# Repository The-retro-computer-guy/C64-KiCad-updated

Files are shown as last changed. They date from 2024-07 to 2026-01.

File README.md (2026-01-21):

# The C64 250407 replica

A replica of the Commodore 64 Ver.250407  Rev.B motherboard, and matching schematics.

The replica project was started by Michael K. (Der Alte Bastler) in 2019 to learn SprintLayout, and the process of reverse engineering printed circuit boards. I finished the layout in SprintLayout, and imported it to KiCad. The KU motherboard schematics are nowhere to be found on the internet. Therefore I used the 250407 Reb.B schematics as reference and then modified them to match the KU motherboard layout.

The board has been prototyped and tested by Langwell Cowan and I.

We are not the first to reverse engineer this board; but we are the first to share the design files online.

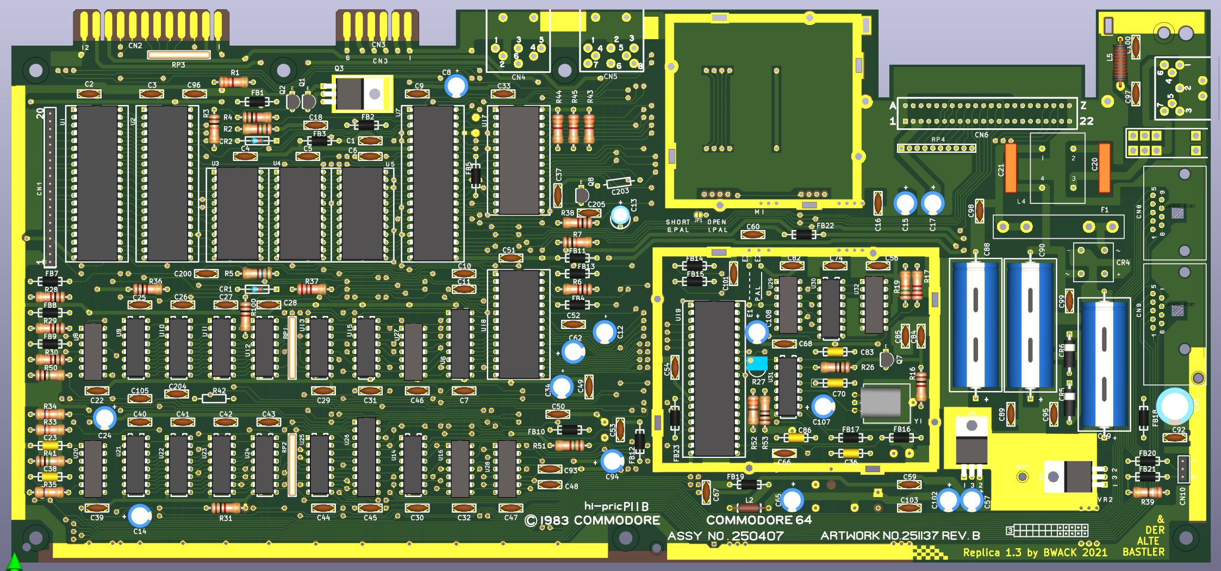
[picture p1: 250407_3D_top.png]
screenshot top

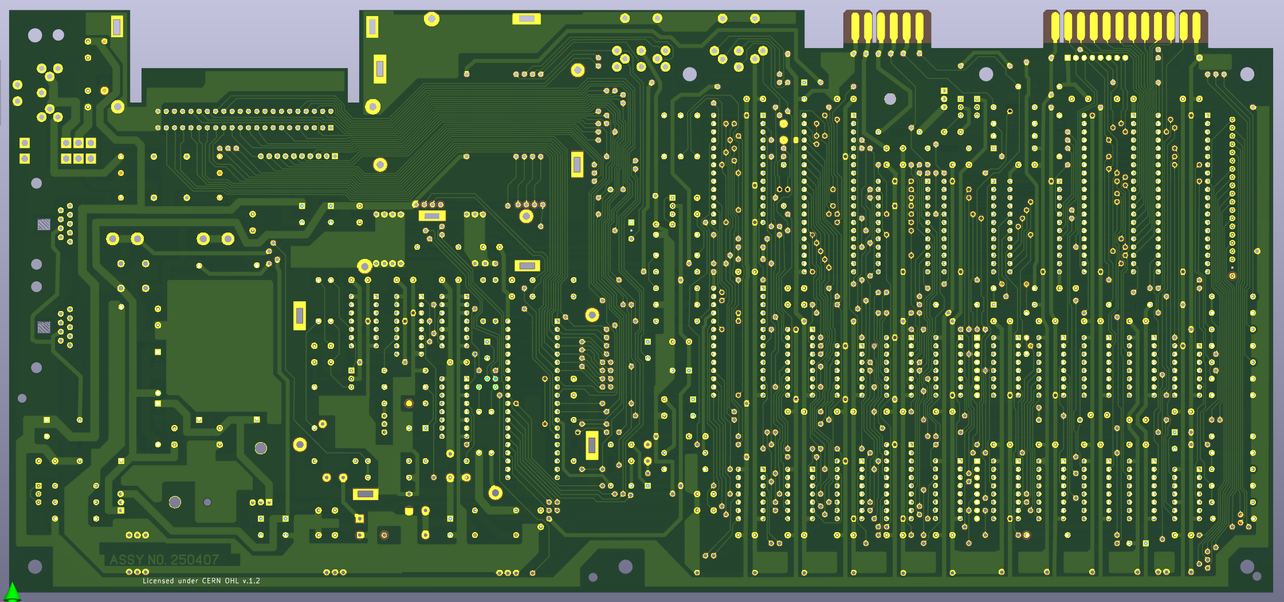
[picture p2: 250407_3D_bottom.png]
screenshot bottom


# BOM

Please see the [BOM file](250407_bom.csv).

Note that some values were left blank because they depend on the clock circuit (PAL/NTSC), and PLA model. They never made it into the schematics. You can find them in a table to the right of the schematics for 250407.
http://www.zimmers.net/anonftp/pub/cbm/schematics/computers/c64/index.html

# Interactive-BOM

[The interactive bom html page](https://htmlpreview.github.io/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) is a useful tool for assembling the board and finding signal traces via a web browser. To order parts, Use the BOM document listed above. (Mouser and Digikey compatable)



# Schematics

Download the PDF file [250407_.pdf](250407_.pdf) for high quality schematics.
Checkout [this tweet](https://twitter.com/paulrickards/status/1371988589974847492) by Paul Rickards where he plots the KU motherboard schematics KU-14194HB :-)

# Change log
- 2025-06-09: PCB and Schematics V1.3: PAL-NTSC jumpers fox. Thank you, Fred Sauer!
Note: V1.3 was opened and saved in KiCAD 9.0.1. I've verified the new gerbers. Things to beware of I you want to modify the design: 1. If you try to load changes from schematic into the PCBNew, KiCAD will require you to annotate the schematics, which in turn will replace all the resistor array sub parts. Example R1A will become R1A1, which will turn into new parts in PCBNew. Therefore I have not done that in this update. I have only changed the silkscreen, and I have only edited the schematics. 2. KiCAD will ask you to refill the zone fills. I have not done that because it also warns you about some change in fill-constrains. I don't remember exactly what, but I did not refill the fill zones when going to V1.3.
- 2022-08-18: Schematics V1.2: symbol and ERC fixes (Pull request from Gabriele Gorla/GGLABS)
- 2020-06-19: PCB and schematics V1.1: First release
- 2020-04-22: PCB and schematics V1.0: Prototype

# YouTube

Part 1-4:

IMAGE ALT TEXT HERE (https://www.youtube.com/watch?v=ox3BLlNSVFU)
IMAGE ALT TEXT HERE (https://www.youtube.com/watch?v=tBIvXRH-Mj0)
IMAGE ALT TEXT HERE (https://www.youtube.com/watch?v=Mg0gVhXbaxc)
IMAGE ALT TEXT HERE (https://www.youtube.com/watch?v=UPUVA1PZOOk)

# License and Disclaimer

Copyright Bwack 2025

This documentation describes Open Hardware and is licensed under the CERN OHL v. 1.2.

You may redistribute and modify this documentation under the terms of theCERN OHL v.1.2. (http://ohwr.org/cernohl). This documentation is distributed WITHOUT ANY EXPRESS OR IMPLIED WARRANTY, INCLUDING OF MERCHANTABILITY, SATISFACTORY QUALITY AND FITNESS FOR APARTICULAR PURPOSE. Please see the CERN OHL v.1.2 for applicable conditions.

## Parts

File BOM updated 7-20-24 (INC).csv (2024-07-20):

54 | 0.1 | Cap MLCC 0.1uF 50V X7R P5.08mm Radial | 80-C322C104K5R5TA | Order Quantity | Manufacturer Name | Datasheet URL | Quoted Part Number | Order Price | Min\Mult Order Qty
15 | 10uF | Cap Alu 10uF 25V 5x5mm P2.5mm Radial | 667-ECE-A1EKS100I | 15 | Panasonic | https://www.mouser.com/datasheet/2/315/ABA0000C1059-947582.pdf | 667-ECE-A1EKS100I | $0.12 | 1\1
2 | 470pF | Cap MLCC 470pF X7R Axial | 594-A471K15X7RF5UAA | 2 | Vishay | https://www.vishay.com/doc?45164 | 594-A471K15X7RF5UAA | $0.26 | 1\1
1 | 2200uF | Cap Elyt 2200uF 16V 15x30mm Axial | 594-2222-021-16222 | 1 | Vishay | https://www.vishay.com/doc?28264 | 594-2222-021-16222 | $4.66 | 1\1
2 | 0.22 | Cap Polyester Film 0.22uF 63VAC P10mm | 594-2222-368-25224 | 2 | Vishay | https://www.vishay.com/doc?28171 | 594-2222-368-25224 | $0.65 | 1\1
1 | 360pF | Cap MLCC 350pF 50V C0G Axial | 594-A331J15C0GF5TAA | 1 | Vishay | https://www.vishay.com/doc?45164 | 594-A331J15C0GF5TAA | $0.31 | 1\1
1 | 20pF | Cap MLCC 20pF C0G Axial | 581-SA102A200JAR | 1 | KYOCERA AVX | https://www.mouser.com/datasheet/2/40/SASprinGuard-1158830.pdf | 581-SA102A200JAR | $0.47 | 1\1
1 | 51pF | Cap MLCC 51pF (47pF OK) X7R Axial | 581-SA102A470JAR | 1 | KYOCERA AVX | https://www.mouser.com/datasheet/2/40/SASprinGuard-1158830.pdf | 581-SA102A470JAR | $0.37 | 1\1
2 | 1800pF | Cap MLCC 1800pF X7R Axial | 581-SA101C182KAR | 2 | KYOCERA AVX | https://www.mouser.com/datasheet/2/40/SASprinGuard-1158830.pdf | 581-SA101C182KAR | $0.43 | 1\1
1 | 15pF 5% | Cap MLCC 15pF 50V 5% C0G Axial/Radial Leaded | 594-A150J15C0GH5TAA | 1 | Vishay | https://www.vishay.com/doc?45164 | 594-A150J15C0GH5TAA | $0.31 | 1\1
1 | 0.47 | Cap MLCC 0.47uF +80/-20% X7R P5.08mm Radial | 80-C330C474K5R | 1 | KEMET | https://www.mouser.com/datasheet/2/447/KEM_C1050_GOLDMAX_X7R-3316381.pdf | 80-C330C474K5R | $0.43 | 1\1
2 | 82pF | Cap MLCC 82pF 100V C0G Axial / Radial Disc | 80-C410C820J1G | 2 | KEMET | https://www.mouser.com/datasheet/2/447/KEM_C1040_AXIMAX_C0G-3316406.pdf | 80-C410C820J1G | $0.31 | 1\1
1 | 1000uF | Cap Elyt 1000uF 16V 20% 10x30mm Axial | 594-2222-021-15102 | 1 | Vishay | https://www.vishay.com/doc?28264 | 594-2222-021-15102 | $3.71 | 1\1
1 | 470uF | Cap Elyt 470uF 50V 20% 13x26mm Axial | 598-477TTA050M | 1 | Cornell Dubilier | https://www.cde.com/resources/catalogs/TTA.pdf | 598-477TTA050M | $2.25 | 1\1
1 | 100uF | Cap Elyt 100uF 16V 20% 6.3x11mm Radial | REA101M1CBK-0611P | 1 | Lelon | https://www.mouser.com/datasheet/2/231/lelon_REA[1]-1174811.pdf | 140-REA101M1CBK0611P |  | 1\1
2 | 0.22 | Cap MLCC 0.22uF 50V X7R P5.08mm Radial | 80-C330C224K1R | 2 | KEMET | https://www.mouser.com/datasheet/2/447/KEM_C1050_GOLDMAX_X7R-3316381.pdf | 80-C330C224K1R | $0.38 | 1\1
1 | KEYBOARD_20PIN_MALE | Pin Header 20 POS P2.54mm male vertical | 538-22-28-4204 | 1 | Molex | https://www.molex.com/en-us/products/part-detail/22284204?display=pdf | 538-22-28-4204 | $1.67 | 1\1
1 | LED_CONNECTOR | Pin Header 3 POS P2.54mm male vertical | 538-22-28-4033 | 1 | Molex | https://www.molex.com/en-us/products/part-detail/22284033?display=pdf | 538-22-28-4033 | $0.28 | 1\1
2 | CONTROL_PORT | Standard Connector DSUB E09P RA590 | 571-5747467-1 | 2 | TE Connectivity | https://www.mouser.com/datasheet/2/418/9/ENG_CS_82068_AMPLIMITE_Right_Angle_Posted_Conn_041-3352032.pdf | 571-5747467-1 | $7.10 | 1\1
1 | IN4371 | Zener Diode 2.7V 500mW DO-35-2 | 78-TZX2V7A | 1 | Vishay | https://www.vishay.com/doc?95449 | 78-TZX2V7A | $0.23 | 1\1
1 | IN755 | Zener Diode 7.5V 500mW DO-35-2 | 78-TZX7V5C | 1 | Vishay | https://www.vishay.com/doc?95449 | 78-TZX7V5C | $0.23 | 1\1
1 | BRIDGE_RECTIFIER | Bridge Rectifier 2A 600V Vf=1.05V | 627-S2VB60-5000 | 1 | Shindengen | https://www.mouser.com/datasheet/2/366/J534S2VB-1203088.pdf | 627-S2VB60-5000 | $2.49 | 1\1
2 | 1N4001 | Rectifier 1A Vr=50V | 625-1N4001-E3/54 | 2 | Vishay | https://www.vishay.com/doc?88840 | 625-1N4001-E3/54 | $0.33 | 1\1
2 | 1A | Fuse Clips (buy two) | 504-BK/1A1907-03-R | 2 | Eaton | https://www.mouser.com/datasheet/2/87/eaton_1axxxx_pcb_fuse_clips_atc_atm_blade_data_she-1608562.pdf | 504-BK/1A1907-03-R | $0.70 | 1\1
9 | FERRITE_BEAD | Ferrite Bead D3.5 L4.45mm Axial | 623-2743001112LF | 9 | Fair-Rite | https://www.mouser.com/datasheet/2/150/2743001112-1512844.pdf | 623-2743001112LF | $0.14 | 1\1
13 | FERRITE_NARROW | Ferrite Bead D3.5 L4.45mm Axial | 623-2743001112LF | 13 | Fair-Rite | https://www.mouser.com/datasheet/2/150/2743001112-1512844.pdf | 623-2743001112LF | $0.076 | 1\1
1 | 2.2uH | Inductor 2.2uH 5% Radial | 652-78F2R2J-RC | 1 | Bourns | https://www.mouser.com/datasheet/2/54/78f_series-777133.pdf | 652-78F2R2J-RC | $0.31 | 1\1
1 | CHOKE | Common Mode Choke 250V 3.8mH 2.1A 150mOhms | 80-SSR10V-21038 | 1 | KEMET | https://www.mouser.com/datasheet/2/447/KEM_LF0042_SSR10V_H-3316793.pdf | 80-SSR10V-21038 | $1.92 | 1\1
1 | 1.2uH | Inductor 1.5uH 10% Radial | 542-5800-4R7-RC | 1 | Bourns | https://www.mouser.com/datasheet/2/54/5800_series-776803.pdf | 542-5800-4R7-RC | $1.46 | 1\1
4 | 2SC1815 | Bipolar Transistor TO-92 Vce=60V 400mA | 2SC1815 | 4 | Central Semiconductor | https://my.centralsemi.com/datasheets/2SC1815.PDF | 610-2SC1815-Y | $0.93 | 1\1
1 | TP29B/2SD880 | Bipolar Transistor TO-220 | 512-KSD880YTU | 1 | onsemi | https://www.mouser.com/datasheet/2/308/1/KSD880_D-2314642.pdf | 512-KSD880YTU | $0.77 | 1\1
4 | 3K3 | Resistor 3K3 0207 Axial | 594-MBB02070C3301FC1 | 4 | Vishay | https://www.vishay.com/doc?28919 | 594-MBB02070C3301FC1 | $0.63 | 1\1
2 | 2K7 | Resistor 2K7 0207 Axial | 594-MBB02070C2701FCT | 2 | Vishay | https://www.vishay.com/doc?28919 | 594-MBB02070C2701FCT | $0.36 | 1\1
1 | 15K | Resistor 15K 0207 Axial | 594-MBB02070C1502FC1 | 1 | Vishay | https://www.vishay.com/doc?28919 | 594-MBB02070C1502FC1 | $0.63 | 1\1
2 | 1.5K | Resistor 1K5 0207 Axial | 594-MBB02070C1501FCT | 2 | Vishay | https://www.vishay.com/doc?28919 | 594-MBB02070C1501FCT | $0.16 | 1\1
2 | 100 | Resistor 100 0207 Axial | 594-MBB02070C1000FCT | 2 | Vishay | https://www.vishay.com/doc?28919 | 594-MBB02070C1000FCT | $0.10 | 1\1
1 | 500 | Trimmer Resistor 500 Ohms Linear | 652-3306F-1-501 | 1 | Bourns | https://www.mouser.com/datasheet/2/54/3306-776934.pdf | 652-3306F-1-501 | $0.49 | 1\1
10 | 1K | Resistor 1K 0207 Axial | 594-MBB02070C1001FCT | 10 | Vishay | https://www.vishay.com/doc?28919 | 594-MBB02070C1001FCT | $0.095 | 1\1
2 | 10K | Resistor 10K 0207 Axial | 594-MBB02070C1002FCT | 2 | Vishay | https://www.vishay.com/doc?28919 | 594-MBB02070C1002FCT | $0.36 | 1\1
2 | 47K | Resistor 47K 0207 Axial | 594-MBB02070C4702FC1 | 2 | Vishay | https://www.vishay.com/doc?28919 | 594-MBB02070C4702FC1 | $0.50 | 1\1
1 | 470K | Resistor 470K 0207 Axial | 594-MBB02070C4703FCT | 1 | Vishay | https://www.vishay.com/doc?28919 | 594-MBB02070C4703FCT | $0.36 | 1\1
1 | 390 | Resistor 390 0207 Axial | 594-MBB02070C3900FCT | 1 | Vishay | https://www.vishay.com/doc?28919 | 594-MBB02070C3900FCT | $0.36 | 1\1
2 | 1M | Resistor 1M 0207 Axial | 594-MBB02070C1004FCT | 2 | Vishay | https://www.vishay.com/doc?28919 | 594-MBB02070C1004FCT | $0.16 | 1\1
1 | 560 | Resistor 560 0207 Axial | 594-MBB02070C5600FCT | 1 | Vishay | https://www.vishay.com/doc?28919 | 594-MBB02070C5600FCT | $0.36 | 1\1
1 | 330 | Resistor 330 0207 Axial | 594-MBB02070C3300FCT | 1 | Vishay | https://www.vishay.com/doc?28919 | 594-MBB02070C3300FCT | $0.16 | 1\1
2 | 33 | Resistor Network 33R Isolated 8 pin SIP | 652-4308R-2LF-33 | 2 | Bourns | https://www.mouser.com/datasheet/2/54/4300R-777281.pdf | 652-4308R-2LF-33 | $2.19 | 1\1
1 | R_ARRAY_7WAY_US | Resistor Network 3K3 Bussed 8 pin SIP | 774-77081332P | 1 | CTS | https://www.mouser.com/datasheet/2/96/770-786259.pdf | 774-77081332P | $3.49 | 1\1
1 | R_ARRAY_9WAY_US | Resistor Network 3K3 Bussed 10 pin SIP | 774-770101332P | 1 | CTS | https://www.mouser.com/datasheet/2/96/770-786259.pdf | 774-770101332P | $3.90 | 1\1
1 | 74LS258 | QUADRUPLE 2-LINE TO 1-LINE DATA SELECTORS/MULTIPLEXERS | 595-SN74LS258BN | 1 | Texas Instruments | https://www.ti.com/lit/gpn/sn74ls257b | 595-SN74LS258BN | $1.10 | 1\1
1 | 74LS139 | DUAL 2-LINE TO 4-LINE DECODERS/MULTIPLEXERS | 595-SN74LS139AN | 1 | Texas Instruments | https://www.ti.com/lit/gpn/sn54ls139a | 595-SN74LS139AN | $0.78 | 1\1
1 | 556 | DUAL PRECISION TIMERS | 595-NE556N | 1 | Texas Instruments | https://www.ti.com/lit/gpn/ne555 | 595-NE556N | $0.46 | 1\1
2 | 74LS257 | QUADRUPLE 2-LINE TO 1-LINE DATA SELECTORS/MULTIPLEXERS | 595-SN74LS257BN | 2 | Texas Instruments | https://www.ti.com/lit/gpn/sn74ls257b | 595-SN74LS257BN | $0.97 | 1\1
1 | 74LS373 | OCTAL D-TYPE TRANSPARENT LATCHES AND EDGE-TRIGGERED FLIP-FLOPS | 595-SN74LS373N | 1 | Texas Instruments | https://www.ti.com/lit/gpn/sn74ls373 | 595-SN74LS373N | $0.92 | 1\1
1 | 7408 | QUADRUPLE 2-INPUT POSITIVE-AND GATES | 595-SN74LS08N | 1 | Texas Instruments | https://www.ti.com/lit/gpn/sn74ls08 | 595-SN74LS08N | $0.81 | 1\1
2 | 4066 | CMOS Quad Bilateral Switch | 595-CD4066BE | 2 | Texas Instruments | https://www.ti.com/lit/gpn/cd4066b | 595-CD4066BE | $0.87 | 1\1
1 | 74LS74 | DUAL D-TYPE POSITIVE-EDGE-TRIGGERED FLIP-FLOPS WITH PRESET AND CLEAR | 595-SN74LS74AN | 1 | Texas Instruments | https://www.ti.com/lit/gpn/sn74ls74a | 595-SN74LS74AN | $0.57 | 1\1
1 | 74LS193 | SYNCHRONOUS 4-BIT UP/DOWN COUNTERS (DUAL CLOCK WITH CLEAR) | 595-SN74LS193N | 1 | Texas Instruments | https://www.ti.com/lit/gpn/sn74ls193 | 595-SN74LS193N | $1.25 | 1\1
1 | 74LS629N | VOLTAGE-CONTROLLED OSCILLATORS | 595-SN74LS629N | 1 | Texas Instruments | https://www.ti.com/lit/gpn/sn74ls629 | 595-SN74LS629N | $5.93 | 1\1
1 | 7406N | HEX INVERTER BUFFERS/DRIVERSWITH OPEN-COLLECTOR HIGH-VOLTAGE OUTPUTS | 595-SN7406N | 1 | Texas Instruments | https://www.ti.com/lit/gpn/sn7406 | 595-SN7406N | $0.95 | 1\1
1 | 7812 | Linear Voltage Regulators 12V 1A Positive | 863-MC7812CTG | 1 | onsemi | https://www.mouser.com/datasheet/2/308/1/MC7800_D-2315963.pdf | 863-MC7812CTG | $0.62 | 1\1
1 | 7805 | Linear Voltage Regulators 5V 1A Positive | 863-MC7805CTG | 1 | onsemi | https://www.mouser.com/datasheet/2/308/1/MC7800_D-2315963.pdf | 863-MC7805CTG | $0.62 | 1\1
1 | Crystal | Crystals HC49/U | 815-AB-17.734475-B4 | 1 | ABRACON | https://www.mouser.com/datasheet/2/3/ab-39594.pdf | 815-AB-17.734475-B4 | $0.75 | 1\1
4 |  | Socket PDIP 40P P2.54mm W15.24mm DUAL WIPE | 517-4840-6000-CP | 4 | 3M | https://www.mouser.com/datasheet/2/1/28ee42f6da6f8c4339adfd7d572e1cf1acfab337-2951721.pdf | 517-4840-6000-CP | $1.18 | 1\1
2 |  | Socket PDIP 28P P2.54mm W15.24mm DUAL WIPE | 517-4828-6000-CP | 2 | 3M | https://www.mouser.com/datasheet/2/1/28ee42f6da6f8c4339adfd7d572e1cf1acfab337-2951721.pdf | 517-4828-6000-CP | $1.07 | 1\1
3 |  | Socket PDIP 24P P2.54mm W15.24mm DUAL WIPE | 517-4824-6000-CP | 3 | 3M | https://www.mouser.com/datasheet/2/1/28ee42f6da6f8c4339adfd7d572e1cf1acfab337-2951721.pdf | 517-4824-6000-CP | $0.74 | 1\1
1 |  | Socket PDIP 20P P2.54mm W7.62mm DUAL WIPE | 517-4820-3000-CP | 1 | 3M | https://www.mouser.com/datasheet/2/1/28ee42f6da6f8c4339adfd7d572e1cf1acfab337-2951721.pdf | 517-4820-3000-CP | $0.80 | 1\1
1 |  | Socket PDIP 18P P2.54mm W7.62mm DUAL WIPE | 517-4818-3000-CP | 1 | 3M | https://www.mouser.com/datasheet/2/1/28ee42f6da6f8c4339adfd7d572e1cf1acfab337-2951721.pdf | 517-4818-3000-CP | $0.65 | 1\1
14 |  | Socket PDIP 16P P2.54mm W7.62mm DUAL WIPE | 517-4816-3000-CP | 14 | 3M | https://www.mouser.com/datasheet/2/1/28ee42f6da6f8c4339adfd7d572e1cf1acfab337-2951721.pdf | 517-4816-3000-CP | $0.383 | 1\1
7 |  | Socket PDIP 14P P2.54mm W7.62mm DUAL WIPE | 517-4814-3000-CP | 7 | 3M | https://www.mouser.com/datasheet/2/1/28ee42f6da6f8c4339adfd7d572e1cf1acfab337-2951721.pdf | 517-4814-3000-CP | $0.49 | 1\1

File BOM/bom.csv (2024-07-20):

Reference | Quantity | Value | Footprint | Mouser P/N | Reichelt P/N | Other
C96 C22 C47 C3 C2 C9 C105 C39 C46 C18 C1 C99 C98 C92 C95 C89 C59 C103 C68 C74 C67 C84 C56 C66 C82 C200 C44 C28 C43 C27 C42 C26 C41 C25 C40 C29 C4 C5 C6 C33 C31 C30 C7 C32 C45 C101 C60 C54 C53 C16 C49 C50 C52 C51 | 54 | .1 | Cap MLCC 0.1uF 50V X7R P5.08mm Radial | 80-C322C104K5R5TA or 581-SR215C104KART | X7R-5 100N
C8 C24 C57 C102 C65 C17 C94 C15 C13 C34 C62 C12 C14 C107 C108 | 15 | 10uF | Cap Alu 10uF 25V 5x5mm P2.5mm Radial | 667-ECE-A1EKS100I | M 10U 25
C11 C10 | 2 | 470pF | Cap MLCC 470pF X7R Axial | 594-A471K15X7RF5UAA | ?
C19 | 1 | 2200uF | Cap Elyt 2200uF 16V 15x30mm Axial | 594-2222-021-16222 or 594-2222-021-15222 or 598-228TTA016M | COS 105 2200/16
C203 | 1 | ? | KU-14194HB-RevB-KiCad:CAPACITOR_RADIAL_P13.97_L9.9_D3.6 | ~
C204 | 1 | ? | KU-14194HB-RevB-KiCad:CAP_P5.08mm | ~
C205 | 1 | 220pF | KU-14194HB-RevB-KiCad:CAP_P5.08mm | ~
C21 C20 | 2 | .22 | Cap Polyester Film 0.22uF 63VAC P10mm | 594-2222-368-25224 | MKS4-100 220N2
C23 | 1 | 360pF | Cap MLCC 350pF 50V C0G Axial | 594-A331J15C0GF5TAA | ?
C36 | 1 | 20pF | Cap MLCC 20pF C0G Axial | 581-SA102A200JAR | ?
C37 | 1 | 1000pF | KU-14194HB-RevB-KiCad:CAP_P5.08mm | ~
C38 | 1 | 51pF | Cap MLCC 51pF (47pF OK) X7R Axial | 581-SA102A470JAR | ?
C48 C93 | 2 | 1800pF | Cap MLCC 1800pF X7R Axial | 581-SA101C182KAR | ?
C70 | 1 | 15pF 5% | Cap MLCC 15pF 50V 5% C0G Axial/Radial Leaded | 594-A150J15C0GH5TAA | KERKO 15P
C85 | 1 | .47 | Cap MLCC 0.47uF +80/-20% X7R P5.08mm Radial | 80-C330C474K5R or 81-RCER71H474K1K1H3B | Z5U-5 470N
C86 C83 | 2 | 82pF | Cap MLCC 82pF 100V C0G Axial / Radial Disc | 80-C410C820J1G
C88 | 1 | 1000uF | Cap Elyt 1000uF 16V 20% 10x30mm Axial | 594-2222-021-15102 or 598-108TTA016M
C90 | 1 | 470uF | Cap Elyt 470uF 50V 20% 13x26mm Axial | 598-477TTA050M | COS 105 470/50
C91 | 1 | 100uF | Cap Elyt 100uF 16V 20% 6.3x11mm Radial | REA101M1CBK-0611P | FR-A 100U 16
C97 C100 | 2 | .22 | Cap MLCC 0.22uF 50V X7R P5.08mm Radial | 80-C330C224K1R | Z5U-5 220N
CN1 | 1 | KEYBOARD_20PIN_MALE | Pin Header 20 POS P2.54mm male vertical | 538-22-28-4204 | MPE 087-1-020
CN10 | 1 | LED_CONNECTOR | Pin Header 3 POS P2.54mm male vertical | 538-22-28-4033 | RND 205-00624
CN2 | 1 | USER_PORT_CON | KU-14194HB-RevB-KiCad:EDGE_CON_24P | -
CN3 | 1 | CASSETTE_PORT_CON | KU-14194HB-RevB-KiCad:EDGE_CON_12P_TAPE | -
CN4 | 1 | SERIAL_BUS_CON | KU-14194HB-RevB-KiCad:SERIAL_CON_DIN6
CN5 | 1 | AV_CONN | KU-14194HB-RevB-KiCad:AV_CON_DIN8 | -
CN6 | 1 | EXPANSION_PORT | Conn Edge Dual Female 44 POS P2.54mm |  | Digikey: H122591-ND
CN7 | 1 | POWER_CON | KU-14194HB-RevB-KiCad:POWER_CON_D7_250407
CN8 CN9 | 2 | CONTROL_PORT | Standard Connector DSUB E09P RA590 | 571-5747467-1
CR1 | 1 | IN4371 | Zener Diode 2.7V 500mW DO-35-2 | 78-TZX2V7A | ZF 2,7
CR100 CR102 CR101 CR103 | 4 | D_Small_ALT |  | ~
CR2 | 1 | IN755 | Zener Diode 7.5V 500mW DO-35-2 | 78-TZX7V5C | ZF 7,5
CR4 | 1 | BRIDGE_RECTIFIER | Bridge Rectifier 2A 600V Vf=1.05V | 627-S2VB60-5000 | KBPC604 DIO
CR5 CR6 | 2 | 1N4001 | Rectifier 1A Vr=50V | 625-1N4001-E3/54 or 625-1N4001-E3/53
E1 | 1 | JUMPER_WIRE | KU-14194HB-RevB-KiCad:JUMPER_WIRE | -
E2 | 1 | JUMPER_WIRE_DASHED | KU-14194HB-RevB-KiCad:JUMPER_WIRE | -
F1 | 2 | 1A | Fuse Clips (buy two) | 504-BK/1A1907-03-R
FB18 FB4 FB22 FB12 FB14 FB15 FB13 FB10 FB11 | 9 | FERRITE_BEAD | Ferrite Bead D3.5 L4.45mm Axial | 623-2743001112LF or 81-BL01RN1A2A2B | BEAD 8-21
FB7 FB9 FB8 FB5 FB2 FB1 FB3 FB20 FB21 FB17 FB16 FB19 FB23 | 13 | FERRITE_NARROW | Ferrite Bead D3.5 L4.45mm Axial | 623-2743001112LF or 81-BL01RN1A2A2B | BEAD 8-21
JP1 | 1 | Jumper_NC_Small | Jumper:SolderJumper-2_P1.3mm_Bridged_RoundedPad1.0x1.5mm | ~
L2 | 1 | 2.2uH | Inductor 2.2uH 5% Radial | 652-78F2R2J-RC | L-MICC 2,2µ
L4 | 1 | CHOKE | Common Mode Choke 250V 3.8mH 2.1A 150mOhms | 80-SSR10V-21038
L5 | 1 | 1.2uH | Inductor 1.5uH 10% Radial | 542-5800-4R7-RC | L-HBCC 1,5µ
M1 | 1 | MODULATOR_LONGBOARD | KU-14194HB-RevB-KiCad:MODULATOR_PORT_LONGBOARD | -
Q2 Q1 Q7 Q8 | 4 | 2SC1815 | Bipolar Transistor TO-92 Vce=60V 400mA | 2SC1815 | SC 1815
Q3 | 1 | TP29B/2SD880 | Bipolar Transistor TO-220 | 512-KSD880YTU | SD 880
R1 R43 R44 R45 | 4 | 3K3 | Resistor 3K3 0207 Axial | 594-MBB02070C3301FC1 | METALL 3,30K
R17 R37 | 2 | 2K7 | Resistor 2K7 0207 Axial | 594-MBB02070C2701FCT | METALL 2,70K
R19 | 1 | 15K | Resistor 15K 0207 Axial | 594-MBB02070C1502FC1 | METALL 15,0K
R2 R51 | 2 | 1.5K | Resistor 1K5 0207 Axial | 594-MBB02070C1501FCT | 1W 1,5K
R26 R53 | 2 | 100 | Resistor 100 0207 Axial | 594-MBB02070C1000FCT | METALL 100
R27 | 1 | 500 | Trimmer Resistor 500 Ohms Linear | 652-3306F-1-501 | BOU 3386P-1-501
R28 R30 R29 R36 R4 R16 R100 R31 R38 R6 | 10 | 1K | Resistor 1K 0207 Axial | 594-MBB02070C1001FCT | METALL 1,00K
R3 R7 | 2 | 10K | Resistor 10K 0207 Axial | 594-MBB02070C1002FCT | METALL 10,0K
R33 R34 | 2 | 47K | Resistor 47K 0207 Axial | 594-MBB02070C4702FC1 | METALL 47,0K
R35 | 1 | 470K | Resistor 470K 0207 Axial | 594-MBB02070C4703FCT | METALL 470K
R39 | 1 | 390 | Resistor 390 0207 Axial | 594-MBB02070C3900FCT | METALL 390
R41 R50 | 2 | 1M | Resistor 1M 0207 Axial | 594-MBB02070C1004FCT or 603-HHV-25JT-52-1M
R42 | 1 | ~ | KU-14194HB-RevB-KiCad:RESISTOR | - | -
R5 | 1 | 560 | Resistor 560 0207 Axial | 594-MBB02070C5600FCT | METALL 560
R52 | 1 | 330 | Resistor 330 0207 Axial | 594-MBB02070C3300FCT
RP1 RP2 | 2 | 33 | Resistor Network 33R Isolated 8 pin SIP | 652-4308R-2LF-33 or 268-33-RC
RP3 | 1 | R_ARRAY_7WAY_US | Resistor Network 3K3 Bussed 8 pin SIP | 774-77081332P
RP4 | 1 | R_ARRAY_9WAY_US | Resistor Network 3K3 Bussed 10 pin SIP | 774-770101332P
SW1 | 1 | POWER_SWITCH | KU-14194HB-RevB-KiCad:POWER_SWITCH
U1 | 1 | CIA_U1 | KU-14194HB-RevB-KiCad:DIP40 | -
U12 U24 U11 U23 U10 U22 U21 U9 | 8 | 4164-2 | KU-14194HB-RevB-KiCad:DIP16 | -
U14 | 1 | 74LS258 | QUADRUPLE 2-LINE TO 1-LINE DATA SELECTORS/MULTIPLEXERS | 595-SN74LS258BN
U15 | 1 | 74LS139 | DUAL 2-LINE TO 4-LINE DECODERS/MULTIPLEXERS | 595-SN74LS139AN
U17 | 1 | PLA_U17 | KU-14194HB-RevB-KiCad:DIP28 | -
U18 | 1 | 6581 | KU-14194HB-RevB-KiCad:DIP28 | -
U19 | 1 | VIC | KU-14194HB-RevB-KiCad:DIP40 | -
U2 | 1 | CIA_U2 | KU-14194HB-RevB-KiCad:DIP40 | -
U20 | 1 | 556 | DUAL PRECISION TIMERS | 595-NE556N
U25 U13 | 2 | 74LS257 | QUADRUPLE 2-LINE TO 1-LINE DATA SELECTORS/MULTIPLEXERS | 595-SN74LS257BN
U26 | 1 | 74LS373 | OCTAL D-TYPE TRANSPARENT LATCHES AND EDGE-TRIGGERED FLIP-FLOPS | 595-SN74LS373N
U27 | 1 | 7408 | QUADRUPLE 2-INPUT POSITIVE-AND GATES | 595-SN74LS08N
U28 U16 | 2 | 4066 | CMOS Quad Bilateral Switch | 595-CD4066BE
U29 | 1 | 74LS74 | DUAL D-TYPE POSITIVE-EDGE-TRIGGERED FLIP-FLOPS WITH PRESET AND CLEAR | 595-SN74LS74AN
U3 U4 | 2 | 2364A | KU-14194HB-RevB-KiCad:DIP24 BASIC AND KERNAL ROM | -
U30 | 1 | 74LS193 | SYNCHRONOUS 4-BIT UP/DOWN COUNTERS (DUAL CLOCK WITH CLEAR) | 595-SN74LS193N
U31 | 1 | 74LS629N | VOLTAGE-CONTROLLED OSCILLATORS | 595-SN74LS629N
U32 | 1 | MC4044 | KU-14194HB-RevB-KiCad:DIP14 | -
U5 | 1 | 2332A | KU-14194HB-RevB-KiCad:DIP24 CHAR ROM | -
U6 | 1 | 2114 | KU-14194HB-RevB-KiCad:DIP18 COLOR RAM | -
U7 | 1 | 6510_MPU | KU-14194HB-RevB-KiCad:DIP40 | -
U8 | 1 | 7406N | HEX INVERTER BUFFERS/DRIVERSWITH OPEN-COLLECTOR HIGH-VOLTAGE OUTPUTS | 595-SN7406N
VR1 | 1 | 7812 | Linear Voltage Regulators 12V 1A Positive | 863-MC7812CTG
VR2 | 1 | 7805 | Linear Voltage Regulators 5V 1A Positive | 863-MC7805CTG
Y1 | 1 | Crystal | Crystals HC49/U | 815-AB-17.734475-B4
Other:
 | Quantity |  | Description | mouser
 | 4 |  | Socket PDIP 40P P2.54mm W15.24mm DUAL WIPE | 517-4840-6000-CP
 | 2 |  | Socket PDIP 28P P2.54mm W15.24mm DUAL WIPE | 517-4828-6000-CP
 | 3 |  | Socket PDIP 24P P2.54mm W15.24mm DUAL WIPE | 517-4824-6000-CP
 | 1 |  | Socket PDIP 20P P2.54mm W7.62mm DUAL WIPE | 517-4820-3000-CP
 | 1 |  | Socket PDIP 18P P2.54mm W7.62mm DUAL WIPE | 517-4818-3000-CP
 | 14 |  | Socket PDIP 16P P2.54mm W7.62mm DUAL WIPE | 517-4816-3000-CP
 | 7 |  | Socket PDIP 14P P2.54mm W7.62mm DUAL WIPE | 517-4814-3000-CP

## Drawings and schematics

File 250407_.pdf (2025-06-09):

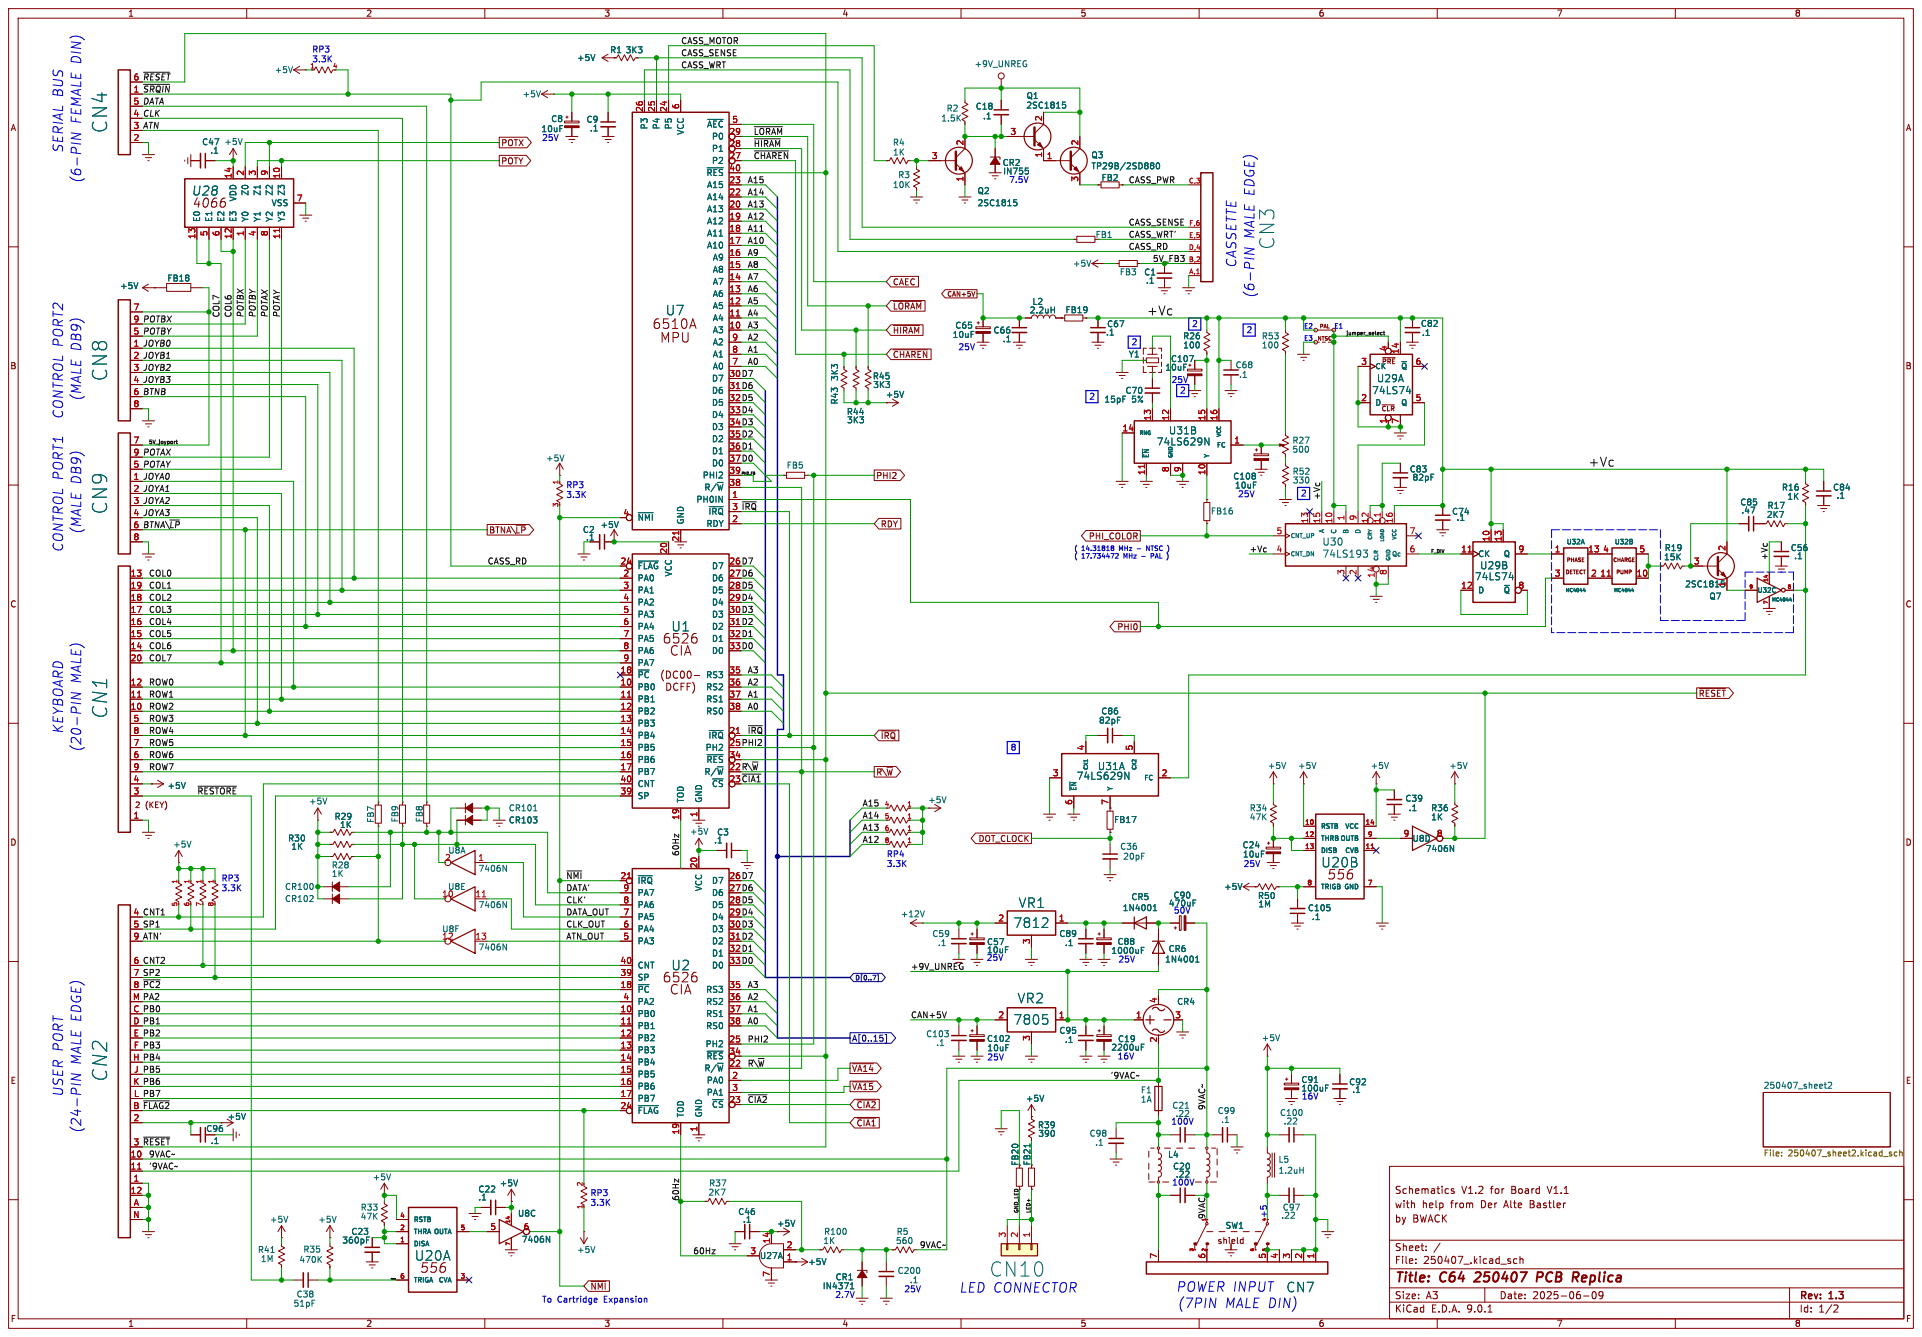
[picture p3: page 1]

6 GND 21 ~{AEC}5 P0 29 P1 28 P2 27 ~{RES}40 A15 23 A14 22 A13 20 A12 19 A11 18 A10 17 A9 16 A8 15 A7 14 A6 13 A5 12 A4 11 A3 10 A2 9 A1 8 A0 7 D7 30 D6 31 D5 32 D4 33 D3 34 D2 35 D1 36 D0 37 PHI2 39 R/~{W}38 PH0IN 1 ~{IRQ}3 RDY 2 U7

6 GND 21 ~{AEC}5 P0 29 P1 28 P2 27 ~{RES}40 A15 23 A14 22 A13 20 A12 19 A11 18 A10 17 A9 16 A8 15 A7 14 A6 13 A5 12 A4 11 A3 10 A2 9 A1 8 A0 7 D7 30 D6 31 D5 32 D4 33 D3 34 D2 35 D1 36 D0 37 PHI2 39 R/~{W}38 PH0IN 1 ~{IRQ}3 RDY 2 U1

9 2 CRY 12 CLR 14 LOAD 11 GND 8 VCC 16

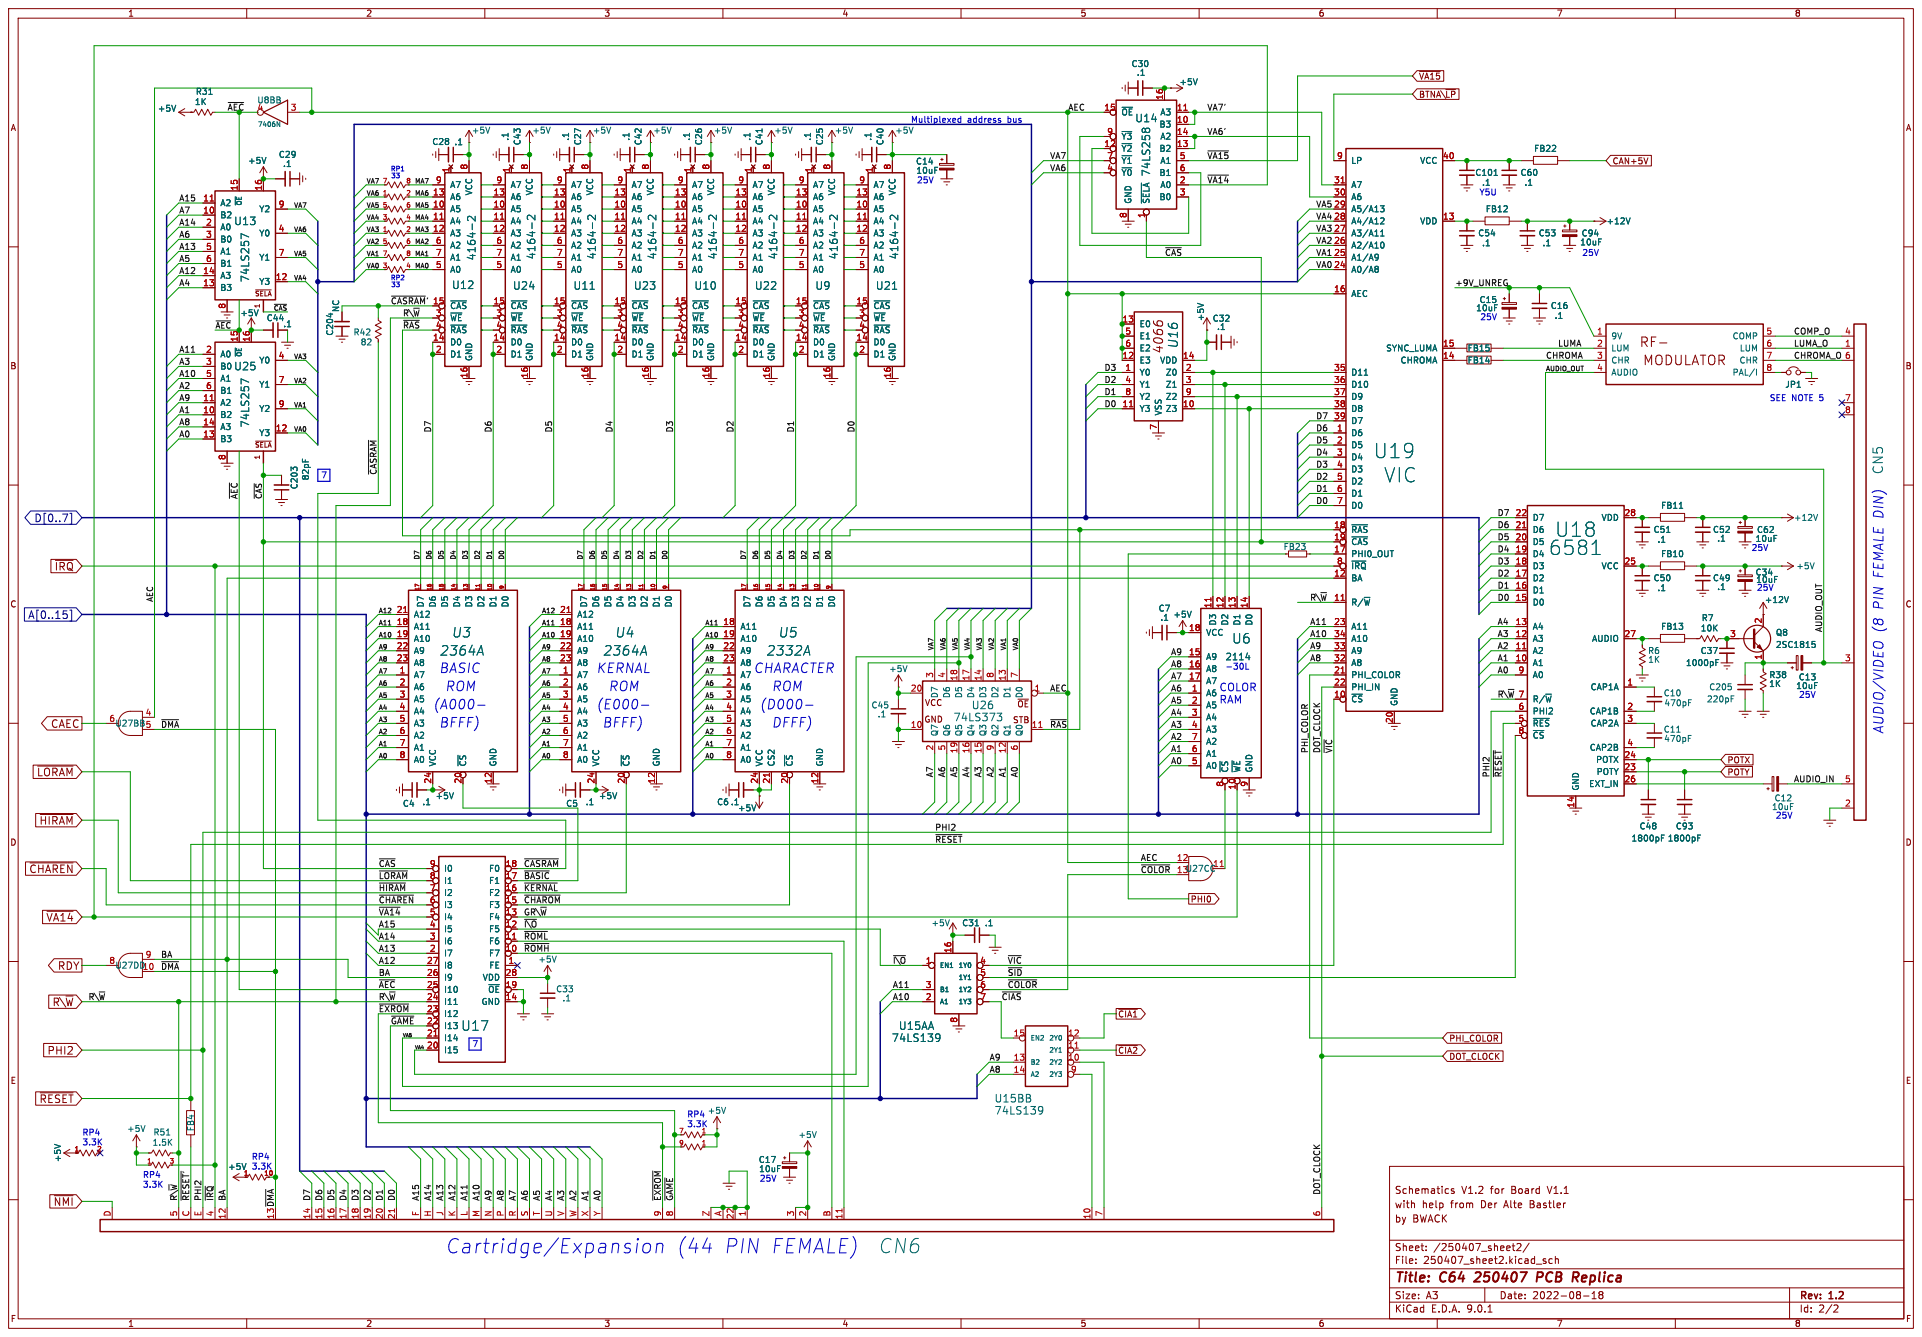
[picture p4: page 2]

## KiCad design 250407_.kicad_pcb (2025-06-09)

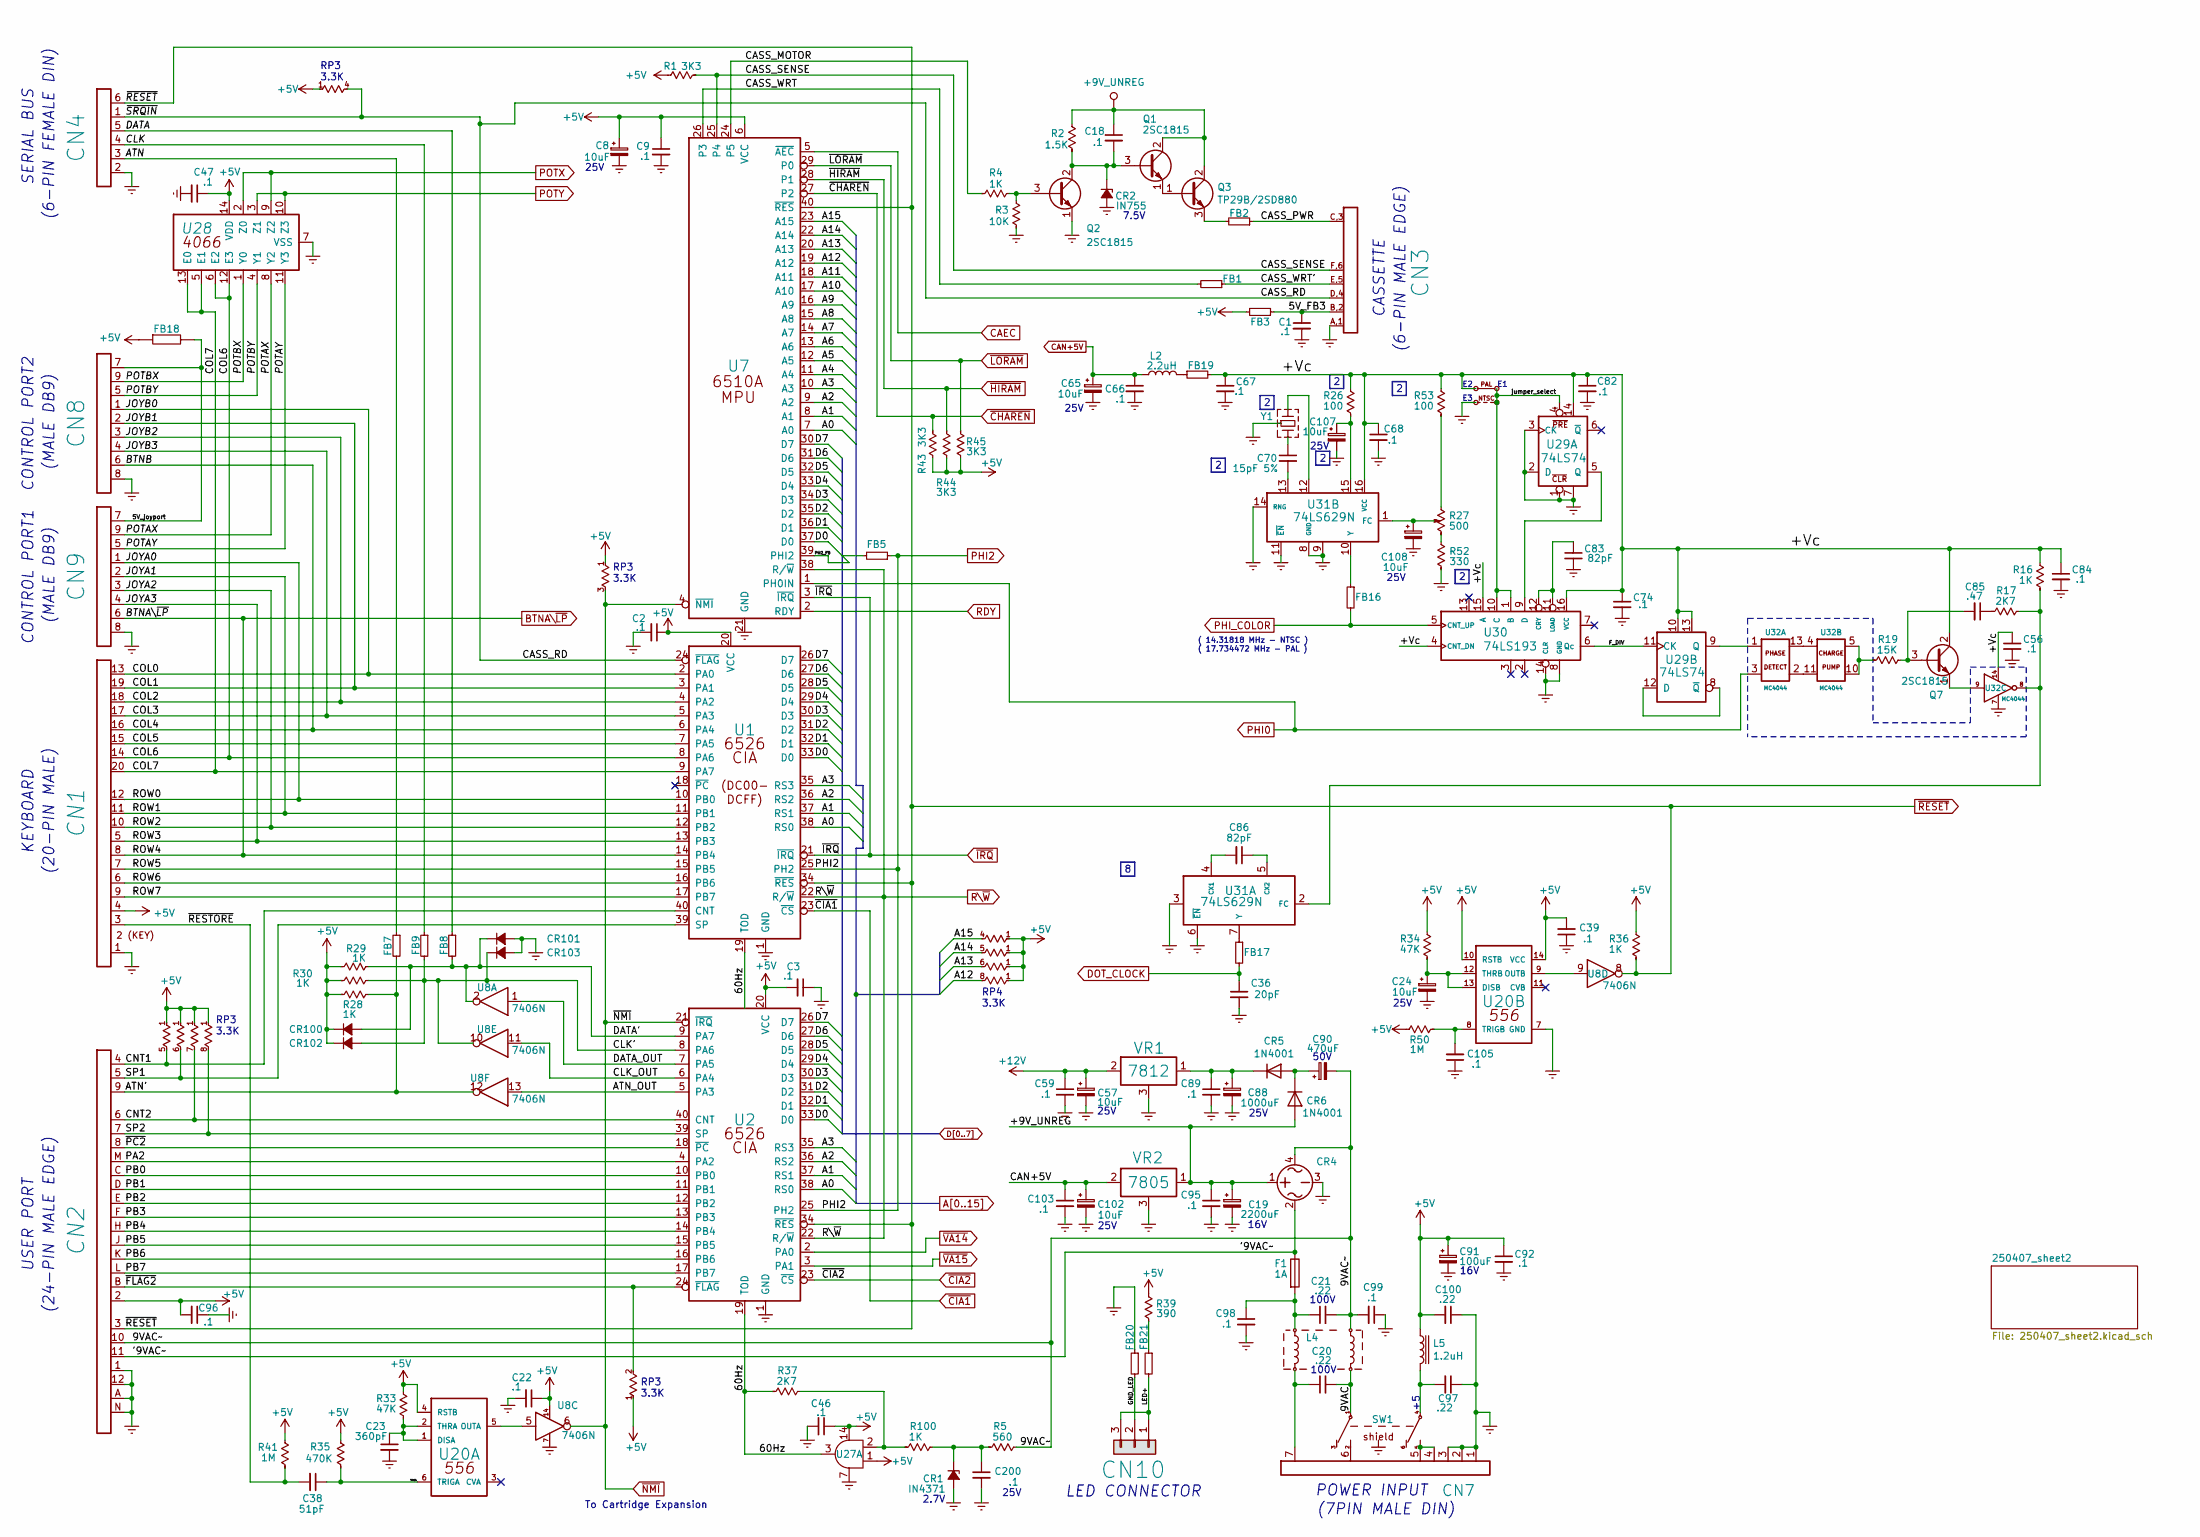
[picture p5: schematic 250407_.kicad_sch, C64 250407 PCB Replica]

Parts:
C1, C2, C3, C9, C18, C22, C39, C46, C47, C56, C59, C66, C67, C68, C74, C82, C84, C89, C92, C95, C96, C98, C99, C103, C105, C200: .1; CAP_P5.08mm
C8, C24, C57, C65, C102, C107, C108: 10uF; CAP_ELYT_RADIAL_P5.08mm_SMALL_RING
C19: 2200uF; LARGE_ELECTROLYTIC_AXIAL_TH
C20, C21: .22; CAP_POLY_100V_TH_P5.08_and_P12.07mm
C23: 360pF; CAP_AXIAL_P12.7mm
C36: 20pF; RESISTOR
C38: 51pF; CAP_AXIAL_P12.7mm
C70: 15pF 5%; RESISTOR
C83, C86: 82pF; RESISTOR
C85: .47; CAP_P5.08mm
C88: 1000uF; LARGE_ELECTROLYTIC_AXIAL_TH
C90: 470uF; LARGE_ELECTROLYTIC_AXIAL_TH
C91: 100uF; CAP_ELYT_RADIAL_P5.08mm
C97, C100: .22; CAP_P5.08mm
CN1: KEYBOARD_20PIN_MALE; KEYBOARD_CON
CN2: USER_PORT_CON; EDGE_CON_24P
CN3: CASSETTE_PORT_CON; EDGE_CON_12P_TAPE
CN4: SERIAL_BUS_CON; SERIAL_CON_DIN6
CN7: POWER_CON; POWER_CON_D7_250407
CN8, CN9: CONTROL_PORT; JOYPORT_DB9
CN10: LED_CONNECTOR; LED_CON
CR1: IN4371; ZENER_12.7mm
CR2: IN755; ZENER_12.7mm
CR4: BRIDGE_RECTIFIER
CR5, CR6: 1N4001; RECTIFIER_TH_P12.7mm
CR100, CR101, CR102, CR103: D_Small_ALT
E1: JUMPER_WIRE
E2: JUMPER_WIRE_DASHED; JUMPER_WIRE
F1: 1A; FUSE
FB1, FB2, FB3, FB5, FB7, FB8, FB9, FB16, FB17, FB18, FB19, FB20, FB21: FERRITE_BEAD; FERRITE_BEAD_TH_P12.7mm
L2: 2.2uH; RESISTOR
L4: CHOKE
L5: 1.2uH; INDUCTOR_P15.24mm
Q1, Q2, Q7: 2SC1815; Q_NPN_ECB
Q3: TP29B/2SD880; TO-220-3_Horizontal_TabDown_250407
R1, R43, R44, R45: 3K3; RESISTOR
R2: 1.5K; RESISTOR
R3: 10K; RESISTOR
R4, R16, R28, R29, R30, R36, R100: 1K; RESISTOR
R5: 560; RESISTOR
R17, R37: 2K7; RESISTOR
R19: 15K; RESISTOR
R26, R53: 100; RESISTOR
R27: 500; POTMETER
R33, R34: 47K; RESISTOR
R35: 470K; RESISTOR
R39: 390; RESISTOR
R41, R50: 1M; RESISTOR
R52: 330; RESISTOR
RP3: 3K3 Bussed; RP_ARRAY_7WAY
RP4: 3K3 Bussed; RP_ARRAY_9WAY
SW1: POWER_SWITCH
U1: CIA_U1; DIP40
U2: CIA_U2; DIP40
U7: 6510_MPU; DIP40
U8: 7406N; DIP14
U20: 556; DIP14
U27: 7408_U27; DIP14
U28: 4066_U28; DIP14
U29: 74LS74; DIP14
U30: 74LS193; DIP16
U31: 74LS629N; DIP16
U32: MC4044; DIP14
VR1: 7812; VREG_TO-220-3_Horizontal_TabDown
VR2: 7805; VREG_TO-220-3_Horizontal_TabDown
Y1: Crystal; CRYSTAL

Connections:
+5V: C2.1, C3.2, C8.1, C9.1, C22.1, C39.2, C46.1, C47.1, C91.1, C92.1, C96.2, C100.2, CN1.4, CN2.2, CR100.1 (K), CR102.1 (K), FB3.2, FB18.1, L5.1, R1.1, R28.2, R29.2, R30.2, R33.1, R34.1, R35.1, R36.1, R39.1, R41.1, R43.1, R44.1, R45.1, R50.1, RP3.1, RP4.1, U1.20 (VCC), U2.20 (VCC), U7.6 (VCC), U8.14, U20.4 (RSTB), U20.10 (RSTB), U20.14 (VCC), U27.1, U27.14, U28.14 (VDD); also elsewhere on the board
+9V_UNREG: C18.1, C19.1, C95.1, CR4.1, CR6.2 (A), Q1.2 (C), Q3.2 (C), R2.1, VR2.1; also elsewhere on the board
+12V: C57.1, C59.1, VR1.2; also elsewhere on the board
/5V_FB3: C1.1, CN3.B,2, FB3.1
/5V_joyport: CN8.7, CN9.7, FB18.2
/9VAC: C20.2, L4.3, SW1.1
/9VAC~: C21.2, C90.2, C99.2, CN2.10, CR4.4, L4.4, R5.1
/60Hz: R37.2, U1.19 (TOD), U2.19 (TOD), U27.3
/250407_sheet2/AEC: U8.3, U27.4, U27.12; also elsewhere on the board
/250407_sheet2/BA: U27.9; also elsewhere on the board
/250407_sheet2/~AEC: U8.4; also elsewhere on the board
/250407_sheet2/~COLOR: U27.13; also elsewhere on the board
/250407_sheet2/~DMA: U27.5, U27.10; also elsewhere on the board
/'9VAC~: CN2.11, CR4.2, F1.1
/ATN: CN4.3, FB7.1
/ATN': CN2.9, FB7.2, R28.1, U8.12
/ATN_OUT: U2.5 (PA3), U8.13
/BTNB: CN1.16, CN8.6, U1.6 (PA4)
/CASS_MOTOR: R4.2, U7.24 (P5)
/CASS_PWR: CN3.C,3, FB2.1
/CASS_RD: CN3.D,4, CN4.1, RP3.4, U1.24 (~FLAG)
/CASS_SENSE: CN3.F,6, R1.2, U7.25 (P4)
/CASS_WRT: FB1.2, U7.26 (P3)
/CASS_WRT': CN3.E,5, FB1.1
/CLK: CN4.4, FB9.1
/CLK': CR102.2 (A), CR103.1 (K), FB9.2, R30.1, U2.8 (PA6), U8.10
/CLK_OUT: U2.6 (PA4), U8.11
/CNT1: CN2.4, RP3.5, U1.40 (CNT)
/CNT2: CN2.6, RP3.7, U2.40 (CNT)
/COL0: CN1.13, CN8.1, U1.2 (PA0)
/COL1: CN1.19, CN8.2, U1.3 (PA1)
/COL2: CN1.18, CN8.3, U1.4 (PA2)
/COL3: CN1.17, CN8.4, U1.5 (PA3)
/COL5: CN1.15, U1.7 (PA5)
/COL6: CN1.14, U1.8 (PA6), U28.6 (E2), U28.12 (E3)
/COL7: CN1.20, U1.9 (PA7), U28.5 (E1), U28.13 (E0)
/DATA: CN4.5, FB8.1
/DATA': CR100.2 (A), CR101.1 (K), FB8.2, R29.1, U2.9 (PA7), U8.2
/DATA_OUT: U2.7 (PA5), U8.1
/F_DIV: U29.11 (CK), U30.6 (Qc)
/GND_LED: CN10.2, FB20.2
/JOYA0: CN1.12, CN9.1, U1.10 (PB0)
/JOYA1: CN1.11, CN9.2, U1.11 (PB1)
/JOYA2: CN1.10, CN9.3, U1.12 (PB2)
/JOYA3: CN1.5, CN9.4, U1.13 (PB3)
/LED+: CN10.1, CN10.3, FB21.2
/PA2: CN2.M, U2.4 (PA2)
/PB0: CN2.C, U2.10 (PB0)
/PB1: CN2.D, U2.11 (PB1)
/PB2: CN2.E, U2.12 (PB2)
/PB3: CN2.F, U2.13 (PB3)
/PB4: CN2.H, U2.14 (PB4)
/PB5: CN2.J, U2.15 (PB5)
/PB6: CN2.K, U2.16 (PB6)
/PB7: CN2.L, U2.17 (PB7)
/PH2_FB: FB5.2, U7.39 (PHI2)
/POTAX: CN9.9, U28.8 (Y2)
/POTAY: CN9.5, U28.11 (Y3)
/POTBX: CN8.9, U28.1 (Y0)
/POTBY: CN8.5, U28.4 (Y1)
/ROW5: CN1.7, U1.15 (PB5)
/ROW6: CN1.6, U1.16 (PB6)
/ROW7: CN1.9, U1.17 (PB7)
/SP1: CN2.5, RP3.6, U1.39 (SP)
/SP2: CN2.7, RP3.8, U2.39 (SP)
/TRIGA: C38.1, R35.2, U20.6 (TRIGA)
/jumper_select: E1.2, E2.2, U29.4, U30.1 (B), U30.10 (C); also elsewhere on the board
/~FLAG2: CN2.B, RP3.2, U2.24 (~FLAG)
/~PC2: CN2.8, U2.18 (~PC)
/~RESTORE: C38.2, CN1.3, R41.2
A0: U1.38 (RS0), U2.38 (RS0), U7.7 (A0); also elsewhere on the board
A1: U1.37 (RS1), U2.37 (RS1), U7.8 (A1); also elsewhere on the board
A2: U1.36 (RS2), U2.36 (RS2), U7.9 (A2); also elsewhere on the board
A3: U1.35 (RS3), U2.35 (RS3), U7.10 (A3); also elsewhere on the board
A4: U7.11 (A4); also elsewhere on the board
A5: U7.12 (A5); also elsewhere on the board
A6: U7.13 (A6); also elsewhere on the board
A7: U7.14 (A7); also elsewhere on the board
A8: U7.15 (A8); also elsewhere on the board
A9: U7.16 (A9); also elsewhere on the board
A10: U7.17 (A10); also elsewhere on the board
A11: U7.18 (A11); also elsewhere on the board
A12: RP4.8, U7.19 (A12); also elsewhere on the board
A13: RP4.6, U7.20 (A13); also elsewhere on the board
A14: RP4.5, U7.22 (A14); also elsewhere on the board
A15: RP4.4, U7.23 (A15); also elsewhere on the board
BTNA\~LP: CN1.8, CN9.6, U1.14 (PB4); also elsewhere on the board
CAEC: U7.5 (~AEC), U27.6
CAN+5V: C65.1, C66.1, C102.1, C103.1, L2.1, VR2.2; also elsewhere on the board
D0: U1.33 (D0), U2.33 (D0), U7.37 (D0); also elsewhere on the board
D1: U1.32 (D1), U2.32 (D1), U7.36 (D1); also elsewhere on the board
D2: U1.31 (D2), U2.31 (D2), U7.35 (D2); also elsewhere on the board
D3: U1.30 (D3), U2.30 (D3), U7.34 (D3); also elsewhere on the board
D4: U1.29 (D4), U2.29 (D4), U7.33 (D4); also elsewhere on the board
D5: U1.28 (D5), U2.28 (D5), U7.32 (D5); also elsewhere on the board
D6: U1.27 (D6), U2.27 (D6), U7.31 (D6); also elsewhere on the board
D7: U1.26 (D7), U2.26 (D7), U7.30 (D7); also elsewhere on the board
DOT_CLOCK: C36.1, FB17.2; also elsewhere on the board
unnamed: C18.2, CR2.1 (K), Q1.3 (B), Q2.2 (C), R2.2
unnamed: C20.1, CN7.7, L4.2
unnamed: C21.1, C98.1, F1.2, L4.1
unnamed: C23.1, R33.2, U20.1 (DISA), U20.2 (THRA)
unnamed: C24.1, R34.2, U20.12 (THRB), U20.13 (DISB)
unnamed: C70.1, Y1.2
unnamed: C70.2, U31.13
unnamed: C83.1, U30.11 (LOAD), U30.12 (CRY)
unnamed: C85.1, R17.2
unnamed: C85.2, Q7.3 (B), R19.1
unnamed: C86.1, U31.5 (CX2)
unnamed: C86.2, U31.4 (CX1)
unnamed: C88.1, C89.1, CR5.1 (K), VR1.1
unnamed: C90.1, CR5.2 (A), CR6.1 (K)
unnamed: C97.2, L5.2, SW1.4
unnamed: C105.2, R50.2, U20.8 (TRIGB)
unnamed: C107.1, R26.2, U31.15
unnamed: C108.1, R27.3, U31.1 (FC)
unnamed: C200.1, CR1.1 (K), R5.2, R100.1
unnamed: CN7.4, CN7.5, SW1.5
unnamed: CN7.6, SW1.2
unnamed: FB2.2, Q3.3 (E)
unnamed: FB16.1, U31.10 (Y)
unnamed: FB17.1, U31.7 (Y)
unnamed: FB19.1, L2.2
unnamed: FB21.1, R39.2
unnamed: Q1.1 (E), Q3.1 (B)
unnamed: Q2.3 (B), R3.1, R4.1
unnamed: Q7.1 (E), U32.9
unnamed: R16.2, R17.1, U31.2 (FC), U32.8
unnamed: R19.2, U32.5, U32.10
unnamed: R27.1, R53.2
unnamed: R27.2, R52.1
unnamed: R37.1, R100.2, U27.2
unnamed: U8.5, U20.5 (OUTA)
unnamed: U8.9, U20.9 (OUTB)
unnamed 220: U27.11; also elsewhere on the board
unnamed: U29.5 (Q), U30.9 (D)
unnamed: U29.9 (Q), U32.1
unnamed: U29.8 (~Q), U29.12 (D)
unnamed: U31.12, Y1.1
unnamed: U32.2, U32.11
unnamed: U32.4, U32.13
PHI0: U7.1 (PH0IN), U32.3; also elsewhere on the board
PHI2: FB5.1, U1.25 (PH2), U2.25 (PH2); also elsewhere on the board
PHI_COLOR: FB16.2, U30.5 (CNT_UP); also elsewhere on the board
POTX: U28.2 (Z0), U28.9 (Z2); also elsewhere on the board
POTY: U28.3 (Z1), U28.10 (Z3); also elsewhere on the board
RDY: U7.2 (RDY), U27.8
R\~W: U1.22 (R/~W), U2.22 (R/~W), U7.38 (R/~W); also elsewhere on the board
~CHAREN: R43.2, U7.27 (P2); also elsewhere on the board
~CIA1: U1.23 (~CS); also elsewhere on the board
~CIA2: U2.23 (~CS); also elsewhere on the board
~HIRAM: R44.2, U7.28 (P1); also elsewhere on the board
~IRQ: U1.21 (~IRQ), U7.3 (~IRQ); also elsewhere on the board
~LORAM: R45.2, U7.29 (P0); also elsewhere on the board
~NMI: RP3.3, U2.21 (~IRQ), U7.4 (~NMI), U8.6; also elsewhere on the board
~RESET: CN2.3, CN4.6, R36.2, U1.34 (~RES), U2.34 (~RES), U7.40 (~RES), U8.8; also elsewhere on the board
~VA14: U2.2 (PA0); also elsewhere on the board
~VA15: U2.3 (PA1); also elsewhere on the board

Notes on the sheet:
RP3 3.3K
CASSETTE
25V
CONTROL PORT1
(6-PIN MALE EDGE)
16V
50V
POWER INPUT
CONTROL PORT2
LED CONNECTOR
(MALE DB9)
(7PIN MALE DIN)
SERIAL BUS
2.7V
RP4 3.3K
( 14.31818 MHz - NTSC ) ( 17.734472 MHz - PAL )
7.5V
100V
(24-PIN MALE EDGE)
USER PORT
KEYBOARD
To Cartridge Expansion
(6-PIN FEMALE DIN)
(20-PIN MALE)

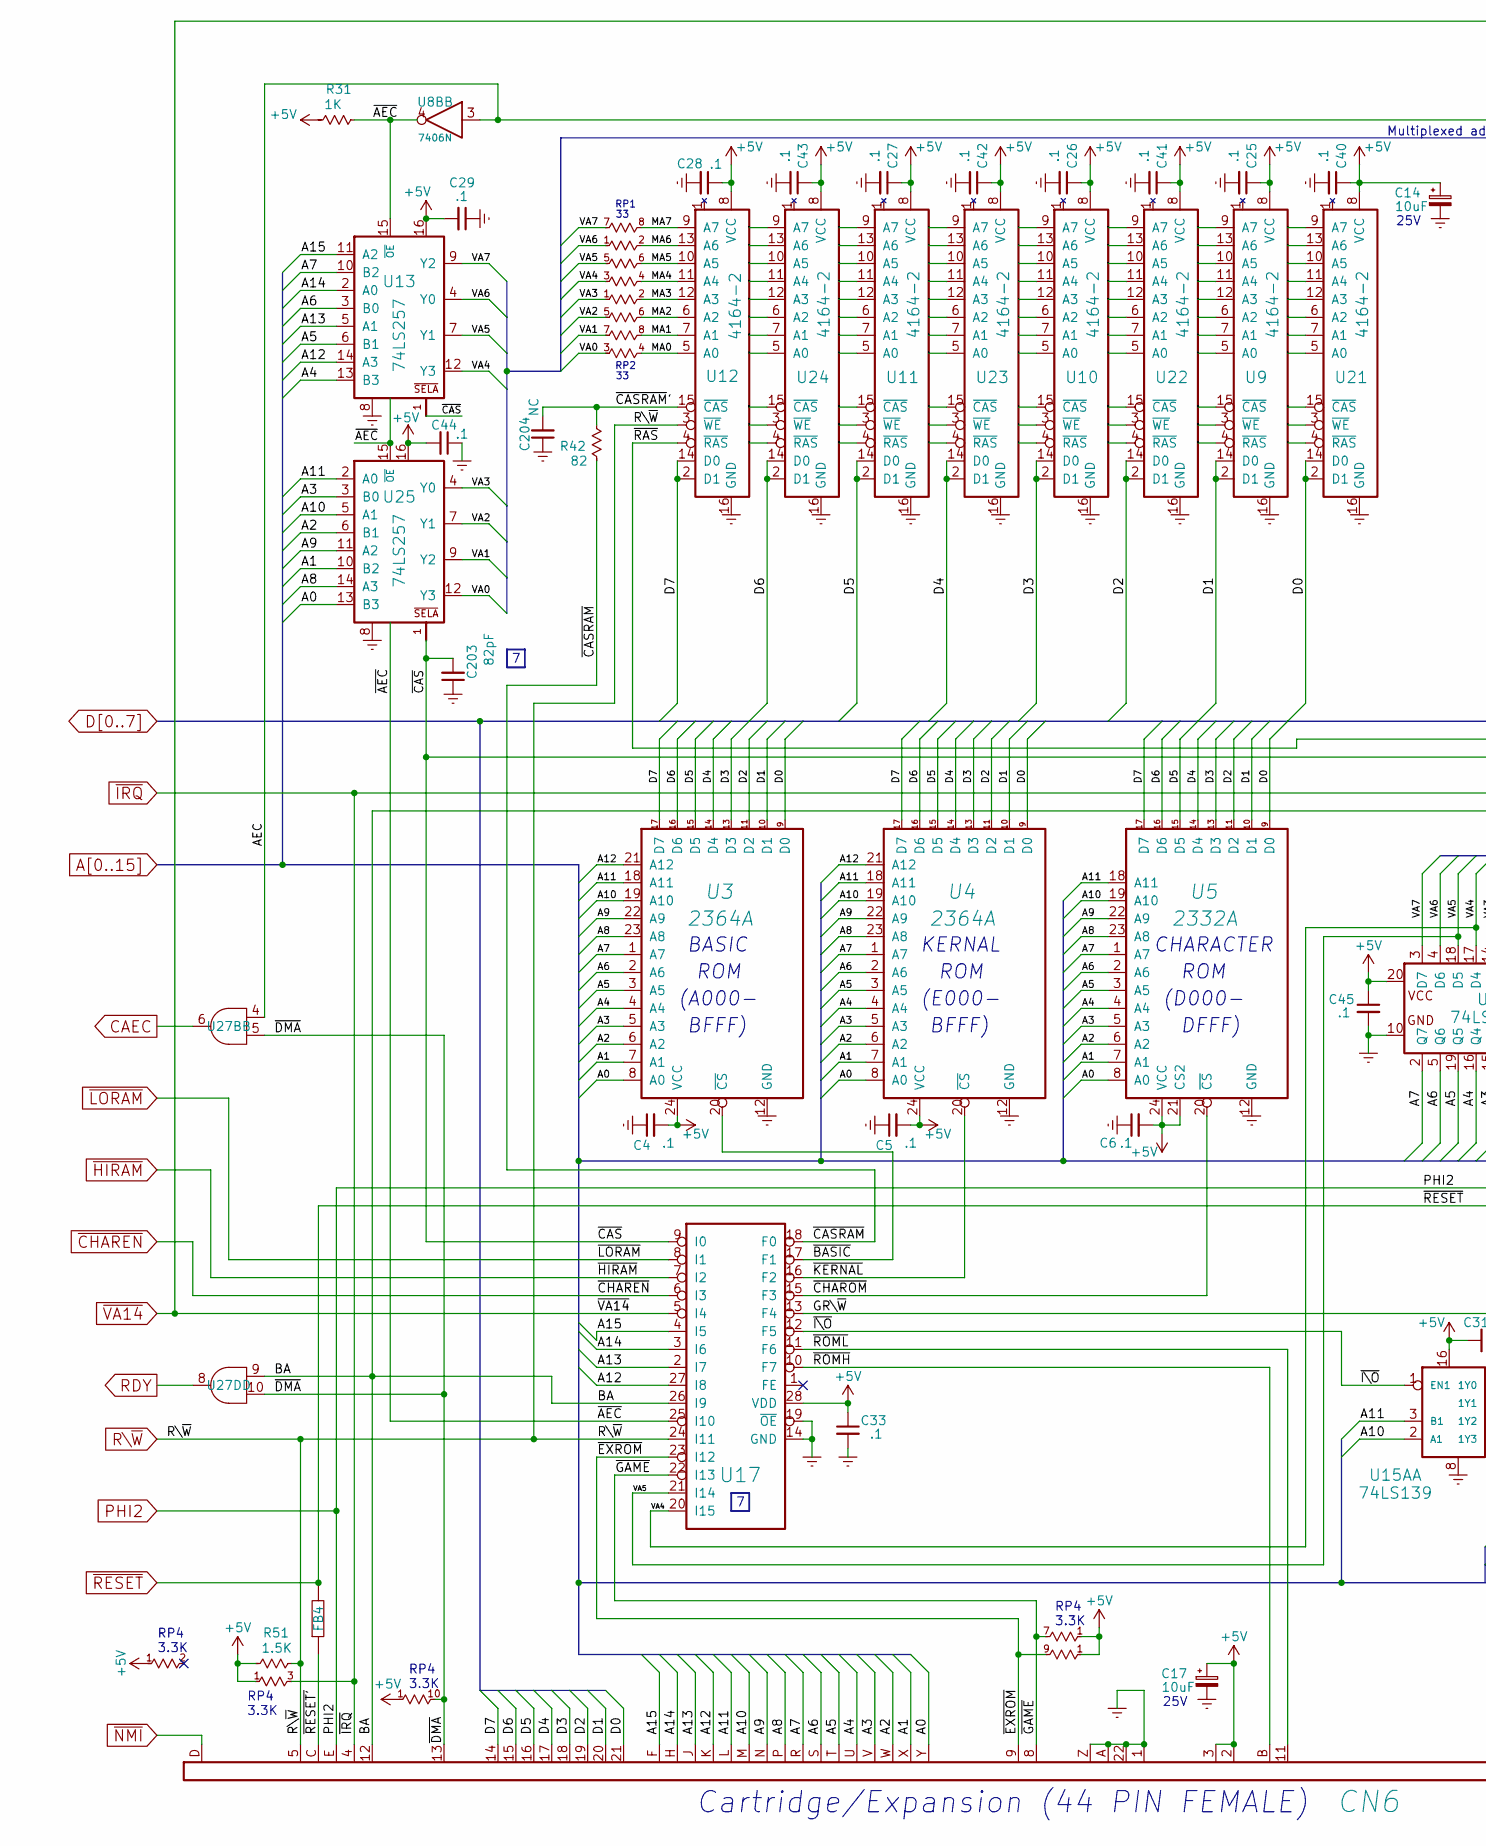
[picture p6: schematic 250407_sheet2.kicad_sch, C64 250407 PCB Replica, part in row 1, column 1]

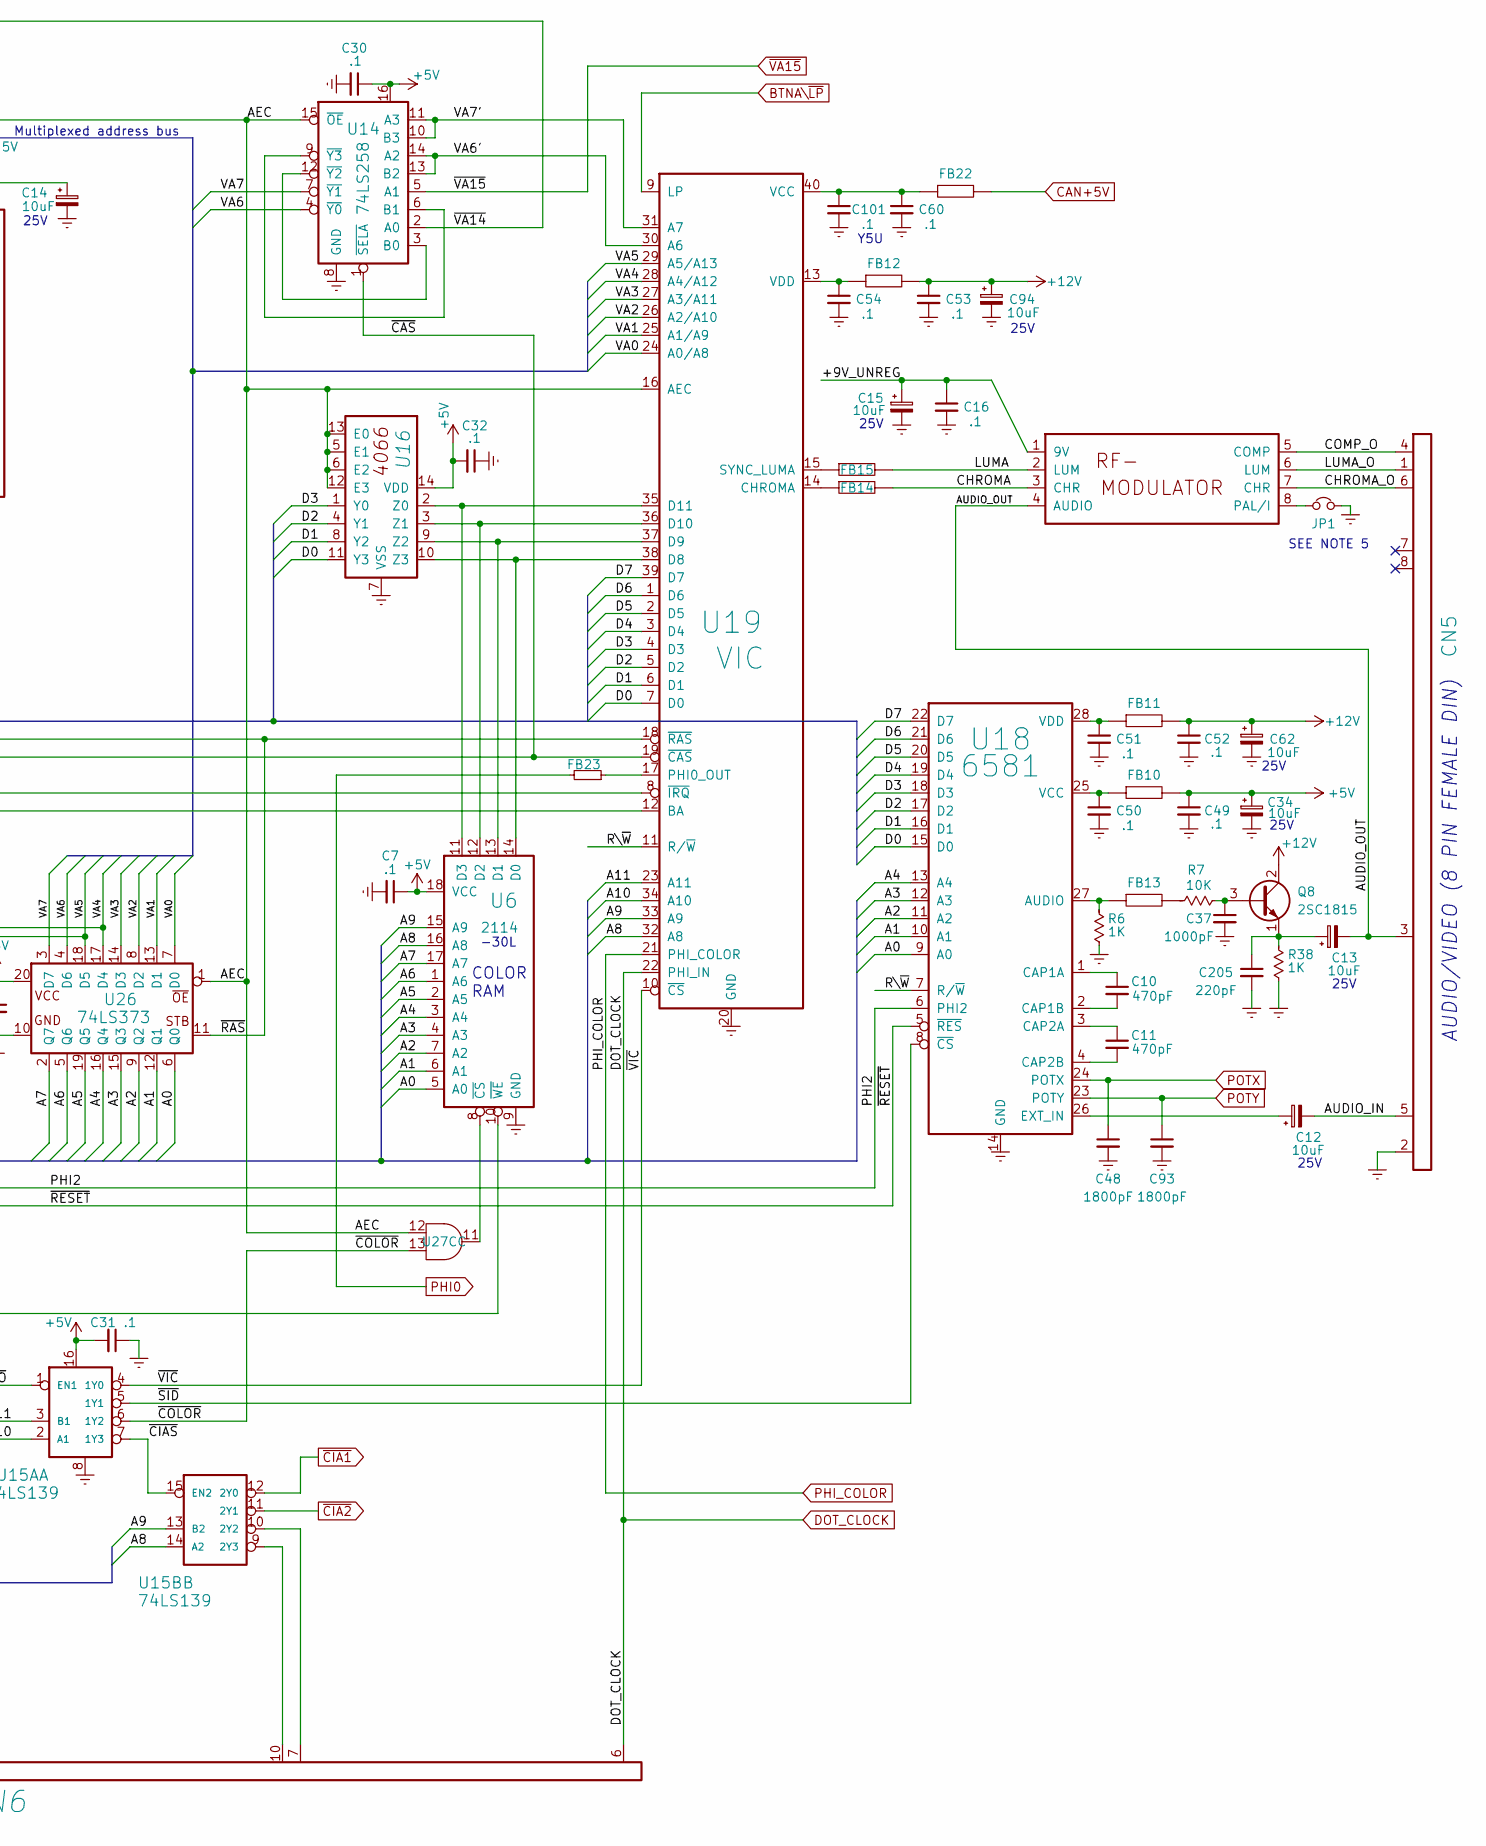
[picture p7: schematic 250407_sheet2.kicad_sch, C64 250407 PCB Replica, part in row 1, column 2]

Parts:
C4, C5, C6, C7, C16, C25, C26, C27, C28, C29, C30, C31, C32, C33, C40, C41, C42, C43, C44, C45, C49, C50, C51, C52, C53, C54, C60, C101: .1; CAP_P5.08mm
C10, C11: 470pF; CAP_P5.08mm
C12, C13, C14, C15, C17, C34, C62, C94: 10uF; CAP_ELYT_RADIAL_P5.08mm_SMALL_RING
C37: 1000pF; CAP_P5.08mm
C48, C93: 1800pF; CAP_P5.08mm
C203: 82pF; CAPACITOR_RADIAL_P13.97_L9.9_D3.6
C204: NC; CAP_P5.08mm
C205: 220pF; CAP_P5.08mm
CN5: AV_CONN; AV_CON_DIN8
CN6: EXPANSION_PORT
FB4, FB10, FB11, FB12, FB13, FB14, FB15, FB22, FB23: FERRITE_BEAD; FERRITE_BEAD_TH_P12.7mm
JP1: Jumper_NC_Small; SolderJumper-2_P1.3mm_Bridged_RoundedPad1.0x1.5mm
M1: MODULATOR_LONGBOARD; MODULATOR_PORT_LONGBOARD
Q8: 2SC1815; Q_NPN_ECB
R6, R31, R38: 1K; RESISTOR
R7: 10K; RESISTOR
R42: 82; RESISTOR
R51: 1.5K; RESISTOR
RP1A, RP1B, RP1C, RP1D, RP2A, RP2B, RP2C, RP2D: 33R isolated; RP_ARRAY_7WAY
RP4: 3K3 Bussed; RP_ARRAY_9WAY
U3, U4: 2364A; DIP24
U5: 2332A; DIP24
U6: 2114; DIP18
U8B: 7406N; DIP14
U9, U10, U11, U12, U21, U22, U23, U24: 4164-2; DIP16
U13, U25: 74LS257; DIP16
U14: 74LS258; DIP16
U15A, U15B: 74LS139; DIP16
U16: 4066_U28; DIP14
U17: PLA_U17; DIP28
U18: 6581; DIP28
U19: VIC; DIP40
U26: 74LS373; DIP20
U27B, U27C, U27D: 7408_U27; DIP14

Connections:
+5V: C4.2, C5.2, C6.2, C7.1, C14.1, C17.1, C25.1, C26.1, C27.1, C28.1, C29.2, C30.1, C31.2, C32.2, C33.1, C34.1, C40.1, C41.1, C42.1, C43.1, C44.2, C45.1, C49.1, CN6.2, CN6.3, FB10.2, R31.2, R51.2, RP4.1, U3.24 (VCC), U4.24 (VCC), U5.21 (CS2), U5.24 (VCC), U6.18 (VCC), U9.8 (VCC), U10.8 (VCC), U11.8 (VCC), U12.8 (VCC), U13.16, U14.16, U15A.16, U16.14 (VDD), U17.28 (VDD), U21.8 (VCC), U22.8 (VCC), U23.8 (VCC), U24.8 (VCC), U25.16, U26.20; also elsewhere on the board
+9V_UNREG: C15.1, C16.1, M1.1 (9V); also elsewhere on the board
+12V: C52.1, C53.1, C62.1, C94.1, FB11.2, FB12.2, Q8.2 (C); also elsewhere on the board
/250407_sheet2/AEC: U8B.3, U14.15 (~OE), U16.5 (E1), U16.6 (E2), U16.12 (E3), U16.13 (E0), U19.16 (AEC), U26.1, U27B.4, U27C.12; also elsewhere on the board
/250407_sheet2/AUDIO_IN: C12.2, CN5.5
/250407_sheet2/AUDIO_OUT: C13.2, CN5.3, M1.4 (AUDIO)
/250407_sheet2/BA: CN6.12, U17.26 (I9), U19.12 (BA), U27D.9; also elsewhere on the board
/250407_sheet2/CHROMA: FB14.2, M1.3 (CHR)
/250407_sheet2/CHROMA_O: CN5.6, M1.7 (CHR)
/250407_sheet2/COMP_O: CN5.4, M1.5 (COMP)
/250407_sheet2/GR\~W: U6.10 (~WE), U17.13 (F4)
/250407_sheet2/LUMA: FB15.2, M1.2 (LUM)
/250407_sheet2/LUMA_O: CN5.1, M1.6 (LUM)
/250407_sheet2/MA0: RP2B.4, U9.5 (A0), U10.5 (A0), U11.5 (A0), U12.5 (A0), U21.5 (A0), U22.5 (A0), U23.5 (A0), U24.5 (A0); also elsewhere on the board
/250407_sheet2/MA1: RP2D.8, U9.7 (A1), U10.7 (A1), U11.7 (A1), U12.7 (A1), U21.7 (A1), U22.7 (A1), U23.7 (A1), U24.7 (A1); also elsewhere on the board
/250407_sheet2/MA2: RP2C.6, U9.6 (A2), U10.6 (A2), U11.6 (A2), U12.6 (A2), U21.6 (A2), U22.6 (A2), U23.6 (A2), U24.6 (A2); also elsewhere on the board
/250407_sheet2/MA3: RP2A.2, U9.12 (A3), U10.12 (A3), U11.12 (A3), U12.12 (A3), U21.12 (A3), U22.12 (A3), U23.12 (A3), U24.12 (A3); also elsewhere on the board
/250407_sheet2/MA4: RP1B.4, U9.11 (A4), U10.11 (A4), U11.11 (A4), U12.11 (A4), U21.11 (A4), U22.11 (A4), U23.11 (A4), U24.11 (A4); also elsewhere on the board
/250407_sheet2/MA5: RP1C.6, U9.10 (A5), U10.10 (A5), U11.10 (A5), U12.10 (A5), U21.10 (A5), U22.10 (A5), U23.10 (A5), U24.10 (A5); also elsewhere on the board
/250407_sheet2/MA6: RP1A.2, U9.13 (A6), U10.13 (A6), U11.13 (A6), U12.13 (A6), U21.13 (A6), U22.13 (A6), U23.13 (A6), U24.13 (A6); also elsewhere on the board
/250407_sheet2/MA7: RP1D.8, U9.9 (A7), U10.9 (A7), U11.9 (A7), U12.9 (A7), U21.9 (A7), U22.9 (A7), U23.9 (A7), U24.9 (A7); also elsewhere on the board
/250407_sheet2/VA0: RP2B.3, U19.24 (A0/A8), U25.12 (Y3), U26.7 (D0); also elsewhere on the board
/250407_sheet2/VA1: RP2D.7, U19.25 (A1/A9), U25.9 (Y2), U26.13 (D1); also elsewhere on the board
/250407_sheet2/VA2: RP2C.5, U19.26 (A2/A10), U25.7 (Y1), U26.8 (D2); also elsewhere on the board
/250407_sheet2/VA3: RP2A.1, U19.27 (A3/A11), U25.4 (Y0), U26.14 (D3); also elsewhere on the board
/250407_sheet2/VA4: RP1B.3, U13.12 (Y3), U17.20 (I15), U19.28 (A4/A12), U26.17 (D4); also elsewhere on the board
/250407_sheet2/VA5: RP1C.5, U13.7 (Y1), U17.21 (I14), U19.29 (A5/A13), U26.18 (D5); also elsewhere on the board
/250407_sheet2/VA6: RP1A.1, U13.4 (Y0), U14.4 (~Y0), U26.4 (D6); also elsewhere on the board
/250407_sheet2/VA6': U14.13 (B2), U14.14 (A2), U19.30 (A6)
/250407_sheet2/VA7: RP1D.7, U13.9 (Y2), U14.7 (~Y1), U26.3 (D7); also elsewhere on the board
/250407_sheet2/VA7': U14.10 (B3), U14.11 (A3), U19.31 (A7)
/250407_sheet2/~AEC: R31.1, U8B.4, U13.15 (~OE), U17.25 (I10), U25.15 (~OE); also elsewhere on the board
/250407_sheet2/~BASIC: U3.20 (~CS), U17.17 (F1)
/250407_sheet2/~CASRAM: R42.2, U17.18 (F0)
/250407_sheet2/~CASRAM': C204.2, R42.1, U9.15 (~CAS), U10.15 (~CAS), U11.15 (~CAS), U12.15 (~CAS), U21.15 (~CAS), U22.15 (~CAS), U23.15 (~CAS), U24.15 (~CAS)
/250407_sheet2/~CAS: C203.2, U13.1 (~SELA), U14.1 (~SELA), U17.9 (I0), U19.19 (~CAS), U25.1 (~SELA)
/250407_sheet2/~CHAROM: U5.20 (~CS), U17.15 (F3)
/250407_sheet2/~DMA: CN6.13, RP4.10, U27B.5, U27D.10; also elsewhere on the board
/250407_sheet2/~EXROM: CN6.9, RP4.9, U17.23 (I12)
/250407_sheet2/~GAME: CN6.8, RP4.7, U17.22 (I13)
/250407_sheet2/~I\O: U15A.1 (EN1), U17.12 (F5); also elsewhere on the board
/250407_sheet2/~KERNAL: U4.20 (~CS), U17.16 (F2)
/250407_sheet2/~RAS: U9.4 (~RAS), U10.4 (~RAS), U11.4 (~RAS), U12.4 (~RAS), U19.18 (~RAS), U21.4 (~RAS), U22.4 (~RAS), U23.4 (~RAS), U24.4 (~RAS), U26.11
/250407_sheet2/~RESET': CN6.C, FB4.1
/250407_sheet2/~ROMH: CN6.B, U17.10 (F7)
/250407_sheet2/~ROML: CN6.11, U17.11 (F6)
/250407_sheet2/~SID: U15A.5 (1Y1), U18.8 (~CS); also elsewhere on the board
/250407_sheet2/~VIC: U15A.4 (1Y0), U19.10 (~CS); also elsewhere on the board
A0: CN6.Y, U3.8 (A0), U4.8 (A0), U5.8 (A0), U6.5 (A0), U18.9 (A0), U25.13 (B3), U26.6 (Q0); also elsewhere on the board
A1: CN6.X, U3.7 (A1), U4.7 (A1), U5.7 (A1), U6.6 (A1), U18.10 (A1), U25.10 (B2), U26.12 (Q1); also elsewhere on the board
A2: CN6.W, U3.6 (A2), U4.6 (A2), U5.6 (A2), U6.7 (A2), U18.11 (A2), U25.6 (B1), U26.9 (Q2); also elsewhere on the board
A3: CN6.V, U3.5 (A3), U4.5 (A3), U5.5 (A3), U6.4 (A3), U18.12 (A3), U25.3 (B0), U26.15 (Q3); also elsewhere on the board
A4: CN6.U, U3.4 (A4), U4.4 (A4), U5.4 (A4), U6.3 (A4), U13.13 (B3), U18.13 (A4), U26.16 (Q4); also elsewhere on the board
A5: CN6.T, U3.3 (A5), U4.3 (A5), U5.3 (A5), U6.2 (A5), U13.6 (B1), U26.19 (Q5); also elsewhere on the board
A6: CN6.S, U3.2 (A6), U4.2 (A6), U5.2 (A6), U6.1 (A6), U13.3 (B0), U26.5 (Q6); also elsewhere on the board
A7: CN6.R, U3.1 (A7), U4.1 (A7), U5.1 (A7), U6.17 (A7), U13.10 (B2), U26.2 (Q7); also elsewhere on the board
A8: CN6.P, U3.23 (A8), U4.23 (A8), U5.23 (A8), U6.16 (A8), U15B.14 (A2), U19.32 (A8), U25.14 (A3); also elsewhere on the board
A9: CN6.N, U3.22 (A9), U4.22 (A9), U5.22 (A9), U6.15 (A9), U15B.13 (B2), U19.33 (A9), U25.11 (A2); also elsewhere on the board
A10: CN6.M, U3.19 (A10), U4.19 (A10), U5.19 (A10), U15A.2 (A1), U19.34 (A10), U25.5 (A1); also elsewhere on the board
A11: CN6.L, U3.18 (A11), U4.18 (A11), U5.18 (A11), U15A.3 (B1), U19.23 (A11), U25.2 (A0); also elsewhere on the board
A12: CN6.K, U3.21 (A12), U4.21 (A12), U13.14 (A3), U17.27 (I8); also elsewhere on the board
A13: CN6.J, U13.5 (A1), U17.2 (I7); also elsewhere on the board
A14: CN6.H, U13.2 (A0), U17.3 (I6); also elsewhere on the board
A15: CN6.F, U13.11 (A2), U17.4 (I5); also elsewhere on the board
BTNA\~LP: U19.9 (LP); also elsewhere on the board
CAN+5V: FB22.2; also elsewhere on the board
D0: CN6.21, U3.9 (D0), U4.9 (D0), U5.9 (D0), U16.11 (Y3), U18.15 (D0), U19.7 (D0), U21.2 (D1), U21.14 (D0); also elsewhere on the board
D1: CN6.20, U3.10 (D1), U4.10 (D1), U5.10 (D1), U9.2 (D1), U9.14 (D0), U16.8 (Y2), U18.16 (D1), U19.6 (D1); also elsewhere on the board
D2: CN6.19, U3.11 (D2), U4.11 (D2), U5.11 (D2), U16.4 (Y1), U18.17 (D2), U19.5 (D2), U22.2 (D1), U22.14 (D0); also elsewhere on the board
D3: CN6.18, U3.13 (D3), U4.13 (D3), U5.13 (D3), U10.2 (D1), U10.14 (D0), U16.1 (Y0), U18.18 (D3), U19.4 (D3); also elsewhere on the board
D4: CN6.17, U3.14 (D4), U4.14 (D4), U5.14 (D4), U18.19 (D4), U19.3 (D4), U23.2 (D1), U23.14 (D0); also elsewhere on the board
D5: CN6.16, U3.15 (D5), U4.15 (D5), U5.15 (D5), U11.2 (D1), U11.14 (D0), U18.20 (D5), U19.2 (D5); also elsewhere on the board
D6: CN6.15, U3.16 (D6), U4.16 (D6), U5.16 (D6), U18.21 (D6), U19.1 (D6), U24.2 (D1), U24.14 (D0); also elsewhere on the board
D7: CN6.14, U3.17 (D7), U4.17 (D7), U5.17 (D7), U12.2 (D1), U12.14 (D0), U18.22 (D7), U19.39 (D7); also elsewhere on the board
DOT_CLOCK: CN6.6, U19.22 (PHI_IN); also elsewhere on the board
unnamed: C10.1, U18.1 (CAP1A)
unnamed: C10.2, U18.2 (CAP1B)
unnamed: C11.1, U18.3 (CAP2A)
unnamed: C11.2, U18.4 (CAP2B)
unnamed: C12.1, U18.26 (EXT_IN)
unnamed: C13.1, C205.1, Q8.1 (E), R38.2
unnamed: C37.1, Q8.3 (B), R7.1
unnamed: C50.1, FB10.1, U18.25 (VCC)
unnamed: C51.1, FB11.1, U18.28 (VDD)
unnamed: C54.1, FB12.1, U19.13 (VDD)
unnamed: C60.1, C101.1, FB22.1, U19.40 (VCC)
unnamed 172: CN6.7, U15B.10 (2Y2); also elsewhere on the board
unnamed 173: CN6.10, U15B.9 (2Y3); also elsewhere on the board
unnamed: FB13.1, R6.2, U18.27 (AUDIO)
unnamed: FB13.2, R7.2
unnamed: FB14.1, U19.14 (CHROMA)
unnamed: FB15.1, U19.15 (SYNC_LUMA)
unnamed: FB23.1, U19.17 (PHI0_OUT)
unnamed: JP1.1, M1.8 (PAL/I)
unnamed: U14.6 (B1), U14.9 (~Y3)
unnamed: U14.3 (B0), U14.12 (~Y2)
unnamed: U15A.6 (1Y2), U27C.13
unnamed: U15A.7 (1Y3), U15B.15 (EN2)
unnamed: U6.11 (D3), U16.2 (Z0), U19.35 (D11)
unnamed: U6.12 (D2), U16.3 (Z1), U19.36 (D10)
unnamed: U6.13 (D1), U16.9 (Z2), U19.37 (D9)
unnamed: U6.14 (D0), U16.10 (Z3), U19.38 (D8)
unnamed 220: U6.8 (~CS), U27C.11; also elsewhere on the board
PHI0: FB23.2; also elsewhere on the board
PHI2: CN6.E, U18.6 (PHI2); also elsewhere on the board
PHI_COLOR: U19.21 (PHI_COLOR); also elsewhere on the board
POTX: C48.1, U18.24 (POTX); also elsewhere on the board
POTY: C93.1, U18.23 (POTY); also elsewhere on the board
R\~W: CN6.5, R51.1, U9.3 (~WE), U10.3 (~WE), U11.3 (~WE), U12.3 (~WE), U17.24 (I11), U18.7 (R/~W), U19.11 (R/~W), U21.3 (~WE), U22.3 (~WE), U23.3 (~WE), U24.3 (~WE); also elsewhere on the board
~CHAREN: U17.6 (I3); also elsewhere on the board
~HIRAM: U17.7 (I2); also elsewhere on the board
~IRQ: CN6.4, RP4.3, U19.8 (~IRQ); also elsewhere on the board
~LORAM: U17.8 (I1); also elsewhere on the board
~NMI: CN6.D; also elsewhere on the board
~RESET: FB4.2, U18.5 (~RES); also elsewhere on the board
~VA14: U14.2 (A0), U17.5 (I4); also elsewhere on the board
~VA15: U14.5 (A1); also elsewhere on the board

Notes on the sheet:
25V
RP4 3.3K
AUDIO/VIDEO (8 PIN FEMALE DIN)
BASIC
DFFF)
RP1
(E000-
ROM
CHARACTER
SEE NOTE 5
Y5U
RP2
Multiplexed address bus
-30L
KERNAL
Cartridge/Expansion (44 PIN FEMALE)
(D000-
(A000-
BFFF)
COLOR RAM

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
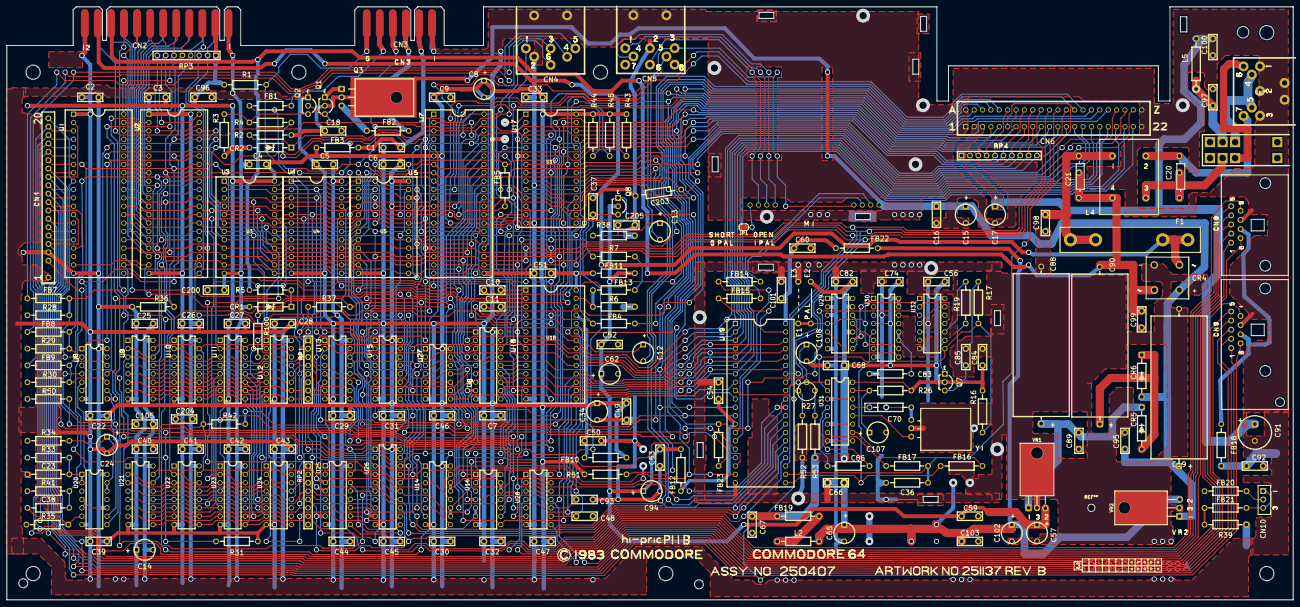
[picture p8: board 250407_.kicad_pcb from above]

Board: 2 copper layers, 390.0 x 179.8 mm, 215 parts (0 on the bottom side), 227 nets.

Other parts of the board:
E3: JUMPER_WIRE
RP1, RP2: 33R isolated; RP_ARRAY_7WAY
U15: 74LS139; DIP16

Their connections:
+5V: U15.16; also elsewhere on the board
/250407_sheet2/MA0: RP2.4; also elsewhere on the board
/250407_sheet2/MA1: RP2.8; also elsewhere on the board
/250407_sheet2/MA2: RP2.6; also elsewhere on the board
/250407_sheet2/MA3: RP2.2; also elsewhere on the board
/250407_sheet2/MA4: RP1.4; also elsewhere on the board
/250407_sheet2/MA5: RP1.6; also elsewhere on the board
/250407_sheet2/MA6: RP1.2; also elsewhere on the board
/250407_sheet2/MA7: RP1.8; also elsewhere on the board
/250407_sheet2/VA0: RP2.3; also elsewhere on the board
/250407_sheet2/VA1: RP2.7; also elsewhere on the board
/250407_sheet2/VA2: RP2.5; also elsewhere on the board
/250407_sheet2/VA3: RP2.1; also elsewhere on the board
/250407_sheet2/VA4: RP1.3; also elsewhere on the board
/250407_sheet2/VA5: RP1.5; also elsewhere on the board
/250407_sheet2/VA6: RP1.1; also elsewhere on the board
/250407_sheet2/VA7: RP1.7; also elsewhere on the board
/250407_sheet2/~CIAS: U15.7, U15.15
/250407_sheet2/~COLOR: U15.6; also elsewhere on the board
/250407_sheet2/~I\O: U15.1; also elsewhere on the board
/250407_sheet2/~SID: U15.5; also elsewhere on the board
/250407_sheet2/~VIC: U15.4; also elsewhere on the board
/jumper_select: E3.2; also elsewhere on the board
A8: U15.14; also elsewhere on the board
A9: U15.13; also elsewhere on the board
A10: U15.2; also elsewhere on the board
A11: U15.3; also elsewhere on the board
unnamed 172: U15.10; also elsewhere on the board
unnamed 173: U15.9; also elsewhere on the board
~CIA1: U15.12; also elsewhere on the board
~CIA2: U15.11; also elsewhere on the board

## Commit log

2024-07-20 Updated BOM
    This Is a BOM containing all the components available for purchase on mouser.com (Not complete) (some parts still need to be sourced)
    [BOM updated 7-20-24 (INC).csv]
2024-07-20 Update and rename BOM updated 7-20-24 (INC).csv to BOM/BOM updated.csv
    [BOM updated.csv]
2024-07-20 Update and rename 10uF.kicad_mod to 10uF.kicad_mod
2025-06-09 V1.3. PAL-NTSC E1 E2 E3 fix. Saved in KiCAD 9.0.1
    [250407_-B_Cu.gbr, 250407_-B_Mask.gbr, 250407_-B_Silkscreen.gbr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]

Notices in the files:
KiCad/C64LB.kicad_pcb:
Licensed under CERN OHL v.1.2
